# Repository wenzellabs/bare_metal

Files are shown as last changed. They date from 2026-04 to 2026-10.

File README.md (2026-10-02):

# bare_metal

**bare metal** is an FPGA development board - the ideal platform to get started with FPGAs and HDL of one or another sort. all open source.

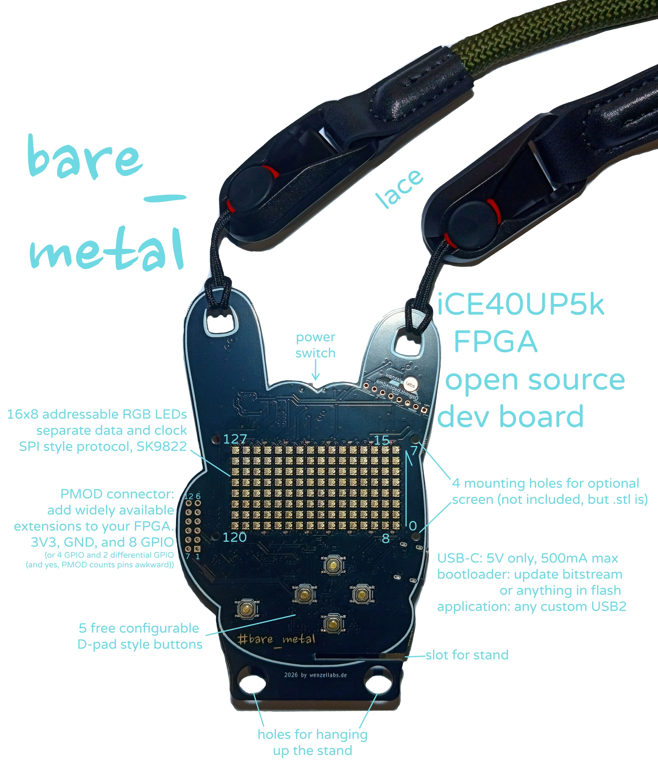
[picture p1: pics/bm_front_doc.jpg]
a black PCB (front) in the shape of a hand showing the metal horn, features are documented


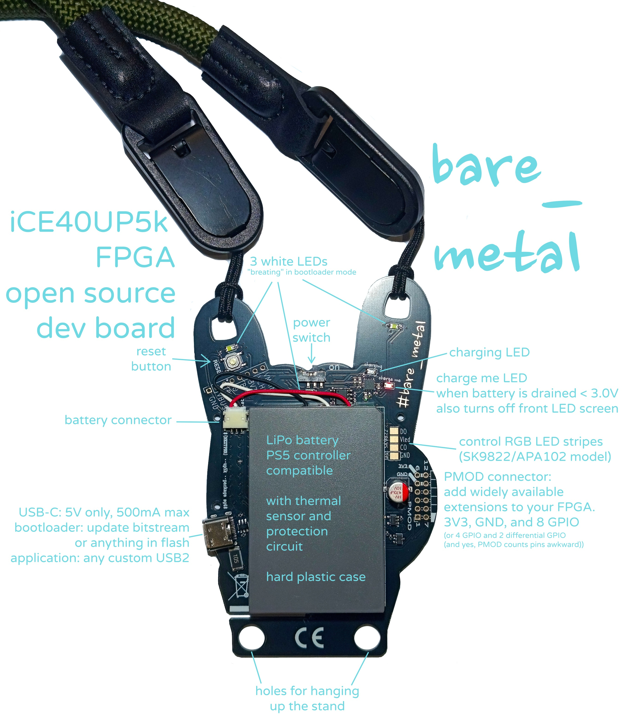
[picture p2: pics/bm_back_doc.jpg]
a black PCB (back) in the shape of a hand showing the metal horn, features are documented


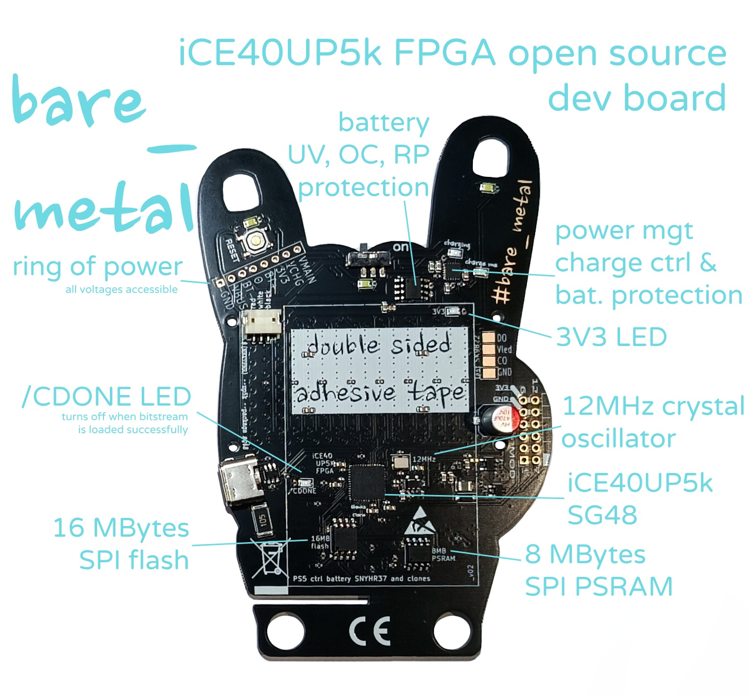
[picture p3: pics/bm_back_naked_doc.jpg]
a black PCB (back, without battery) in the shape of a hand showing the metal horn, features are documented


bare_metal, the opensource FPGA development board:

- five user buttons: OK, left, right, up, down
- large 16x8 SPI-addressable RGB LEDs display
- extensible through a PMOD interface
- comes with a battery for many hours of runtime
- extensive power management, monitoring and battery protection in HW
- allows for CPU-less designs or soft-core CPUs
- get into FPGAs with the **yosys** and **nextpnr** all open source toolchains
- program in python/amarant, verilog, spade or others
- comes with a stand
- three bright white LEDs as simple debug or flashlight
- usable as name tag, comes with a lace
- comes with a bootloader as 1st of four bitstreams
- can host up to 3 user bitstreams
- 16MBytes flash in total (1 bitstream takes < 128kBytes)
- 8MBytes RAM in total
- transputer research platform, as 3 user bitstreams can "boot" each other, see `bootloader` below
- hacky but feasible: more that 3 user bitstreams (hundreds)

## tech bits

### schematic

see the [hardware](hardware/) directory. find [the schematics](hardware/bare_metal_schematic.pdf), the KiCad sources and [some](hardware/bare_metal_front.png) [nice](hardware/bare_metal_back.png) [renderings](hardware/bare_metal_3d.png).

### memory

- 16MBytes SPI flash (W25Q128JVSIQ) this is where the FPGA boots from and user storage such as text, fonts, images, sounds, video, etc.
- 8MBytes SPI PSRAM (LY68L6400) far all of your extensive memory needs

here's a memory map of the SPI flash:

```
# 0x000_0000 - 0x000_009f =160b, multiboot header, slot table
# 0x000_00a0 - 0x001_efff ~124kB, slot 0, bare_metal_bootloader
# 0x001_f000 - 0x001_ffff =4kB, bootmetadata
# 0x002_0000 - 0x003_ffff =128kB, slot 1, user bitstream, hackerstacker_demo by default
# 0x004_0000 - 0x005_ffff =128kB, slot 2, another bitstream, transputers anyone?
# 0x006_0000 - 0x007_ffff ~128kB, slot 3, yab, hooray for transputers!
# 0x008_0000 - 0x100_0000 ~15.5MB, user data, images, fonts, text, sounds, videos etc
```
```
# in hackerstacker_demo, we reserve the first 512 KB for bootloader and bitstreams,
# and use the rest for user data:
# 0x008_0000 - 0x008_ffff = 64 kB, font data
# 0x009_0000 - 0x009_ffff = 64 kB, game data
# 0x00a_0000 - 0x00a_ffff = 64 kB, nick names
# 0x00b_0000 - 0x0ff_ffff = ~15.3MB images, video
```

### bootloader

the bootloader is always started after power up or reset. it lives in slot0 of the four default bitstream slots.

the bootloader is forked from https://github.com/tinyfpga/TinyFPGA-Bootloader which looks unmaintained nowadays. we forked, and implement our bootloader and the `tinyprog` flashing tool at https://codeberg.org/wenzellabs/bare_metal_bootloader

```

                   [-----------][----------][----------]
                   [ user bit- ][ user bit-][ user bit-]
                   [ stream 1  ][ stream 2 ][ stream 3 ]
                   [           ][          ][          ]
                   [===========][==========][==========]
                   [-----------------------------------]
                   [    USB-bootloader bitstream 0     ]
                   [===================================]
               [-------------------------------------------]
               [ iCE40-up5k-sg48 FPGA, 5k LCs, DSP fn()s   ]
               [===========================================]
[-----]    [----------------------------------------------------]    [---------------]
[ USB ]----[ bare_metal, buttons, batt., LEDs, RGB-display, PMOD]----[PMOD extensions]
[=====]    [====================================================]    [===============]

```

the bootloader animates the three white LEDs `index`, `middle` and `pinky`. if the bootloader detects a host PC (if it gets USB enumerated) it stays in the bootloader and creates a cdc_acm /dev/ttyACM0 that can be used in conjunction with tinyprog to flash user bitstreams into slot1, slot2 or slot3, or any other flash content.

if no host PC is detected the bootloader "jumps" to the user bitstream in slot1.

**stay in bootloader** although there's no host PC:

- press btn_**down** while powerup/reset.

jump to **slot1** user bitstrem although we're connected to a host PC:

- press btn_**ok** while powerup/reset.

jump to **slot2** user bitstrem although we're connected to a host PC:

- press btn_**left** while powerup/reset.

jump to **slot3** user bitstrem although we're connected to a host PC:

- press btn_**right** while powerup/reset.

### examples

#### hackerstacker_demo

by default the first user bitstream in slot1 is hackerstacker_demo, that has various modes, which can be advanced by a long btn_ok press.

modes:

- hackerstacker game, control: btn_ok
- scroll user text. control: switch text: btn_ok, brightness: btn_up, btn_down, scroll-mode: btn_left, font: btn-right
- skating images. control: btn_ok
- various static patterns, rainbow, trans flag, checker board. control: btn_ok
- various animated patterns, rainbow, trans flag. control: btn_ok

the texts, fonts and images live in the SPI flash aside from the bitstream, so they can be replaced or extended without re-synthesizing the bitstream.
see [the hackerstacker_demo directory](firmware/examples/amaranth/hackerstacker_demo) and there the make targets
```
make flash-nick # see nick.txt first!
make flash-font
make flash-image # see image.txt first!
```

#### julia

reach it by pressing btn_left while powerup/reset.

by default the second user bitstream in slot2 is julia. it renders a julia set, and loops:

- pan to a random position
- zoom in until the entropy is too low
- zoom out again

the up/down/left/right control the complex coordinate C of the julia set being rendered.

the OK button changes the palette.

#### psram_probe

reach it by pressing btn_right while powerup/reset.

for now the default third user bitstream in slot3 is psram_probe, just a production PSRAM test. lights up one LED in green per pass.

I hope to get some small spade demo, looking at you @TheZoq2.

### power

#### battery

a PS5 controller compatible battery similar to SNYHR37. 2500 mAh, 1S.
the little plasic box is a nice feature to protect the pouch cell from stabbing you and vice versa.

#### USB-C

there's a current limit of 500mA in place. no USB-PD, just 5V.

the data pins are usable and available for creating any USB2 devices. the board has no dedicated USB-HW (aside from ESD protection) but anything can be implemented in the FPGA, just as the bootloader does. related pins:

```
# USB
set_io -nowarn usbp         42    # IOT_51a  - USB D+
set_io -nowarn usbn         38    # IOT_50b  - USB D-
set_io -nowarn usb_det      37    # IOT_36b  - USB_DET, active-high enables 1k5 pull-up on D+
```

#### battery protection

we turn the screen off at around 3V battery voltage to notify the user that she needs a power up. there's also a red `charge me` LED that indicates this state.
at 2.5V a hard battery protection kicks in, and everything is switched off, until charging via USB-C again.

there's also a overvoltage and overcurrent protection and thermal monitoring in place.

#### the ring of power

bare_metal wears a little ring at it's pinky, the `ring of power`.
here all various important voltages are accessible:

- 1 GND
- 2 VBUS
- 3 VBAT_MINUS
- 4 BAT_TEMP_SENSE
- 5 VBAT
- 5 3V3
- 6 VCHG
- 7 VMAIN

## the FPGA

it's a **Lattice iCE40 UP5K** in a **SG48** package

- fully supported by yosys and nextpnr
- 5000+ LUTs
- 8 DSP blocks (MULT16 with ACC32)
- 1024kBits SPRAM in 4 blocks
- 120kBits EBR memory in 30 blocks
- 2 hard I2C blocks
- 2 hard SPI blocks

## pinout

it's all in the examples and printed on the stand, but for completenes here's a PCF:

```
# bare_metal
# iCE40UP5K SG48 (QFN 48)

# this is a complete bare_metal pin definition
# you may use for your designs

# 12 MHz crystal oscillator (dedicated clock pad)
set_io -nowarn clk_12M      35    # IOT_46b_G0

# USB
set_io -nowarn usbp         42    # IOT_51a  - USB D+
set_io -nowarn usbn         38    # IOT_50b  - USB D-
set_io -nowarn usb_det      37    # IOT_36b  - USB_DET, active-high enables 1k5 pull-up on D+

# buttons
set_io -nowarn btn_ok       23    # IOT_37a
set_io -nowarn btn_up       45    # IOB_5b
set_io -nowarn btn_down     11    # IOB_20a
set_io -nowarn btn_left     44    # IOB_3b_G6
set_io -nowarn btn_right    10    # IOB_18a

# LED indicators - three white LEDs, low active
set_io -nowarn led_index    39    # white_index
set_io -nowarn led_middle   40    # white_middle
set_io -nowarn led_pinky    41    # white_pinky

# SPI configuration flash
set_io -nowarn spi_mosi     14    # IOB_32a - SPI_SO, MOSI
set_io -nowarn spi_miso     17    # IOB_33b - SPI_SI, MISO
set_io -nowarn spi_clk      15    # IOB_34a - SPI_SCK
set_io -nowarn spi_csn_flash 16   # IOB_35b - SPI_CSn_FLASH
set_io -nowarn spi_wp       18    # IOB_31b - SPI_WPn
set_io -nowarn spi_hold     19    # IOB_29b - SPI_HOLDn

# SPI PSRAM, same as above, just CSn
set_io -nowarn spi_csn_ram   6    # IOB_13b - SPI_CSn_RAM

# SK9822 / APA102-compatible LED matrix (128 LEDs, 16x8)
set_io -nowarn led_di        4    # IOB_8a
set_io -nowarn led_ci        3    # IOB_9b

# LED matrix power enable
set_io -nowarn led_power_on 46    # IOB_0a

# PMOD interface - mind the special pin numbering of PMOD interfaces!
set_io -nowarn -pullup yes pmod_a_n     27   # PMOD pin 1
set_io -nowarn -pullup yes pmod_a_p     26   # PMOD pin 7
set_io -nowarn -pullup yes pmod_2       25   # PMOD pin 2
set_io -nowarn -pullup yes pmod_8       28   # PMOD pin 8
set_io -nowarn -pullup yes pmod_b_p     32   # PMOD pin 3
set_io -nowarn -pullup yes pmod_b_n     31   # PMOD pin 9
set_io -nowarn -pullup yes pmod_4       13   # PMOD pin 4
set_io -nowarn -pullup yes pmod_10      12   # PMOD pin 10

```

## stand

the stand can serve multiple purposes

it conveniently lists all PMOD and all other pins.

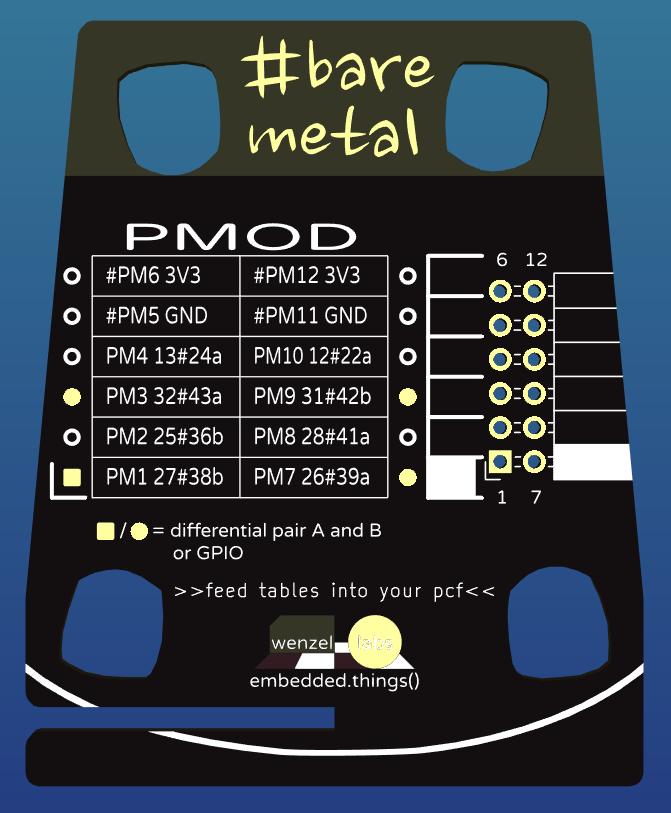
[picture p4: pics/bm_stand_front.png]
a black PCB (front) with pin tabled printed on


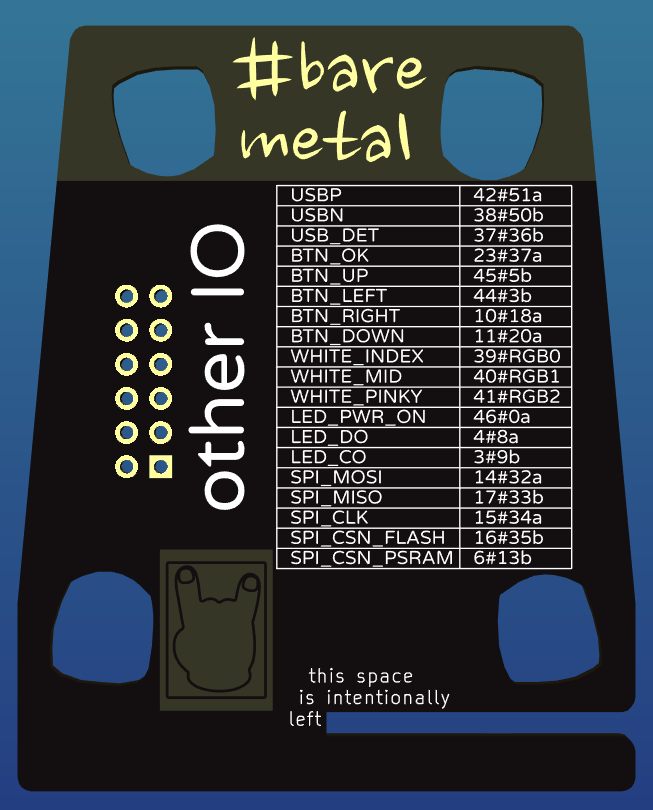
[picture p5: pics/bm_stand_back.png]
a black PCB (back) with pin tabled printed on


use it to display the bare_metal board, by sliding the two slots into each other.

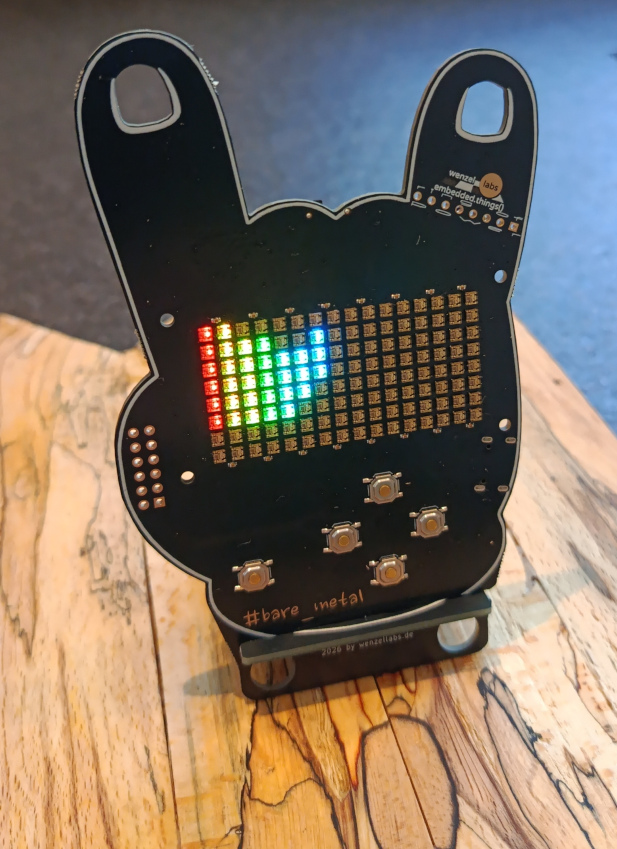
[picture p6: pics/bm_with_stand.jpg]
a black PCB standing on a table


or when hanging the bare_metal around your neck (or elsewhere) you can hang the stand into the bottom holes, the stand then mimicks a sleeve.

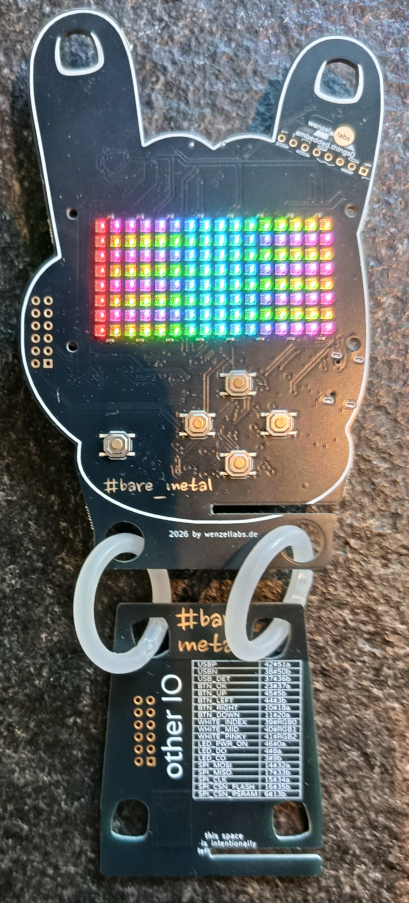
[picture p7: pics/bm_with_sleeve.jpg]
a black hand shaped PCB with a 2nd sleeve shaped PCB


## what's included?

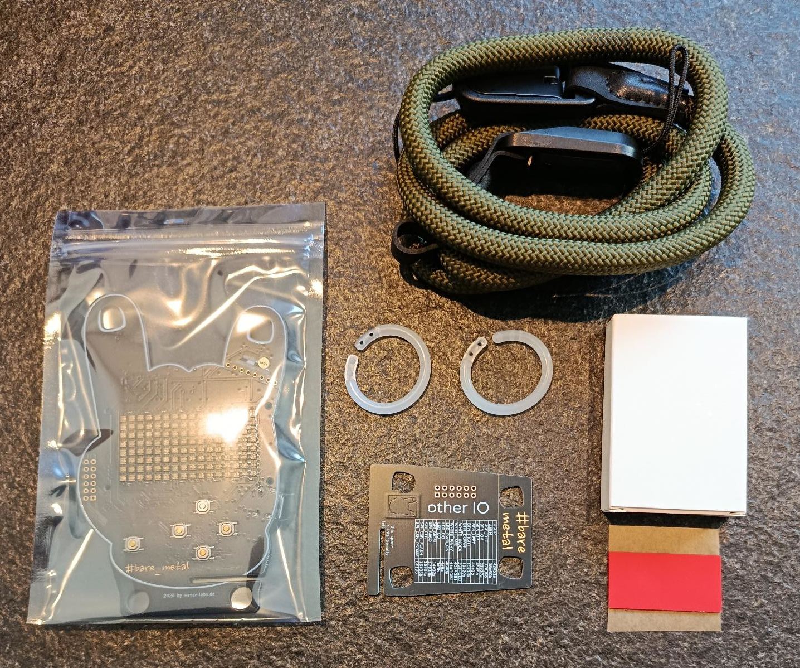
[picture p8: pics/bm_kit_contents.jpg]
the contents in the bare_metal kit


- bare_metal main board
- rugged lace, detachable
- two soft plastic rings to hang bare_metal and its stand together
- the bare_metal stand PCB
- the 1S LiPo battery
- double sided adhesive tape to mount the battery on the bare_metal main board

## license

Copyright (c) 2026 m. wenzel, wenzellabs

Unless otherwise stated, the hardware designs, firmware source code,
and documentation in this repository are licensed under:

Creative Commons Attribution-NonCommercial-ShareAlike 4.0 International
(CC BY-NC-SA 4.0)

https://creativecommons.org/licenses/by-nc-sa/4.0/

Commercial use, including commercial manufacture, sale, or distribution
of products based on these materials, is not permitted without
separate permission from the copyright holder.

see LICENSE.txt

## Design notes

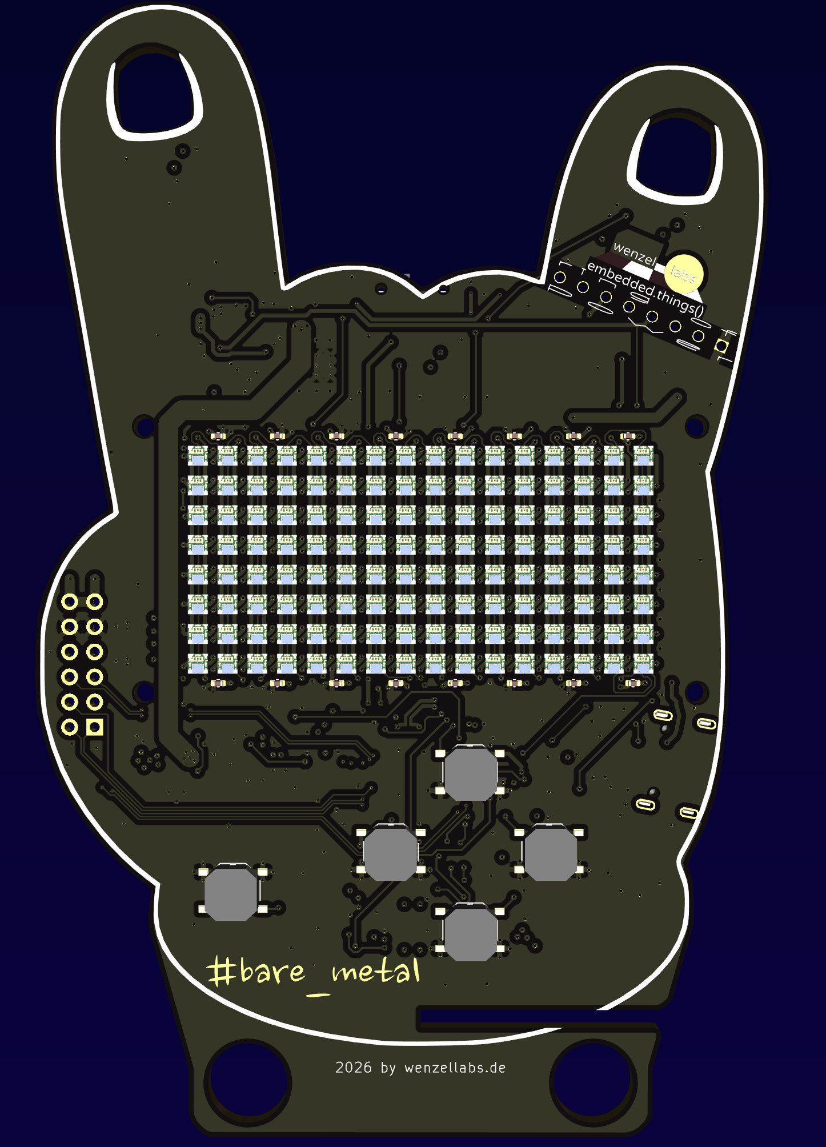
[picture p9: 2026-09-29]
hardware/bare_metal_front.png

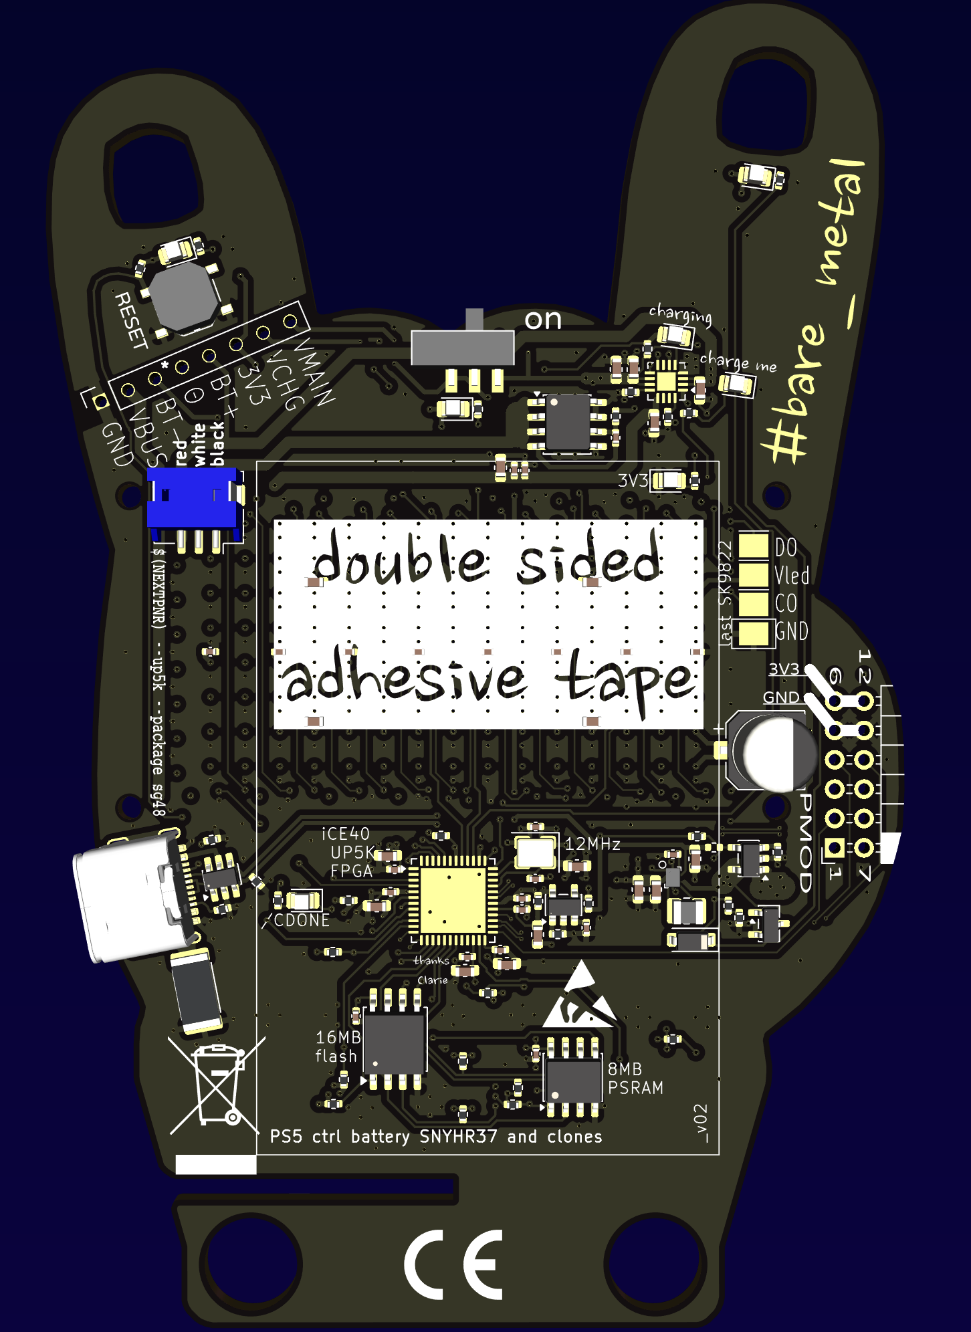
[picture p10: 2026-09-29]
hardware/bare_metal_back.png

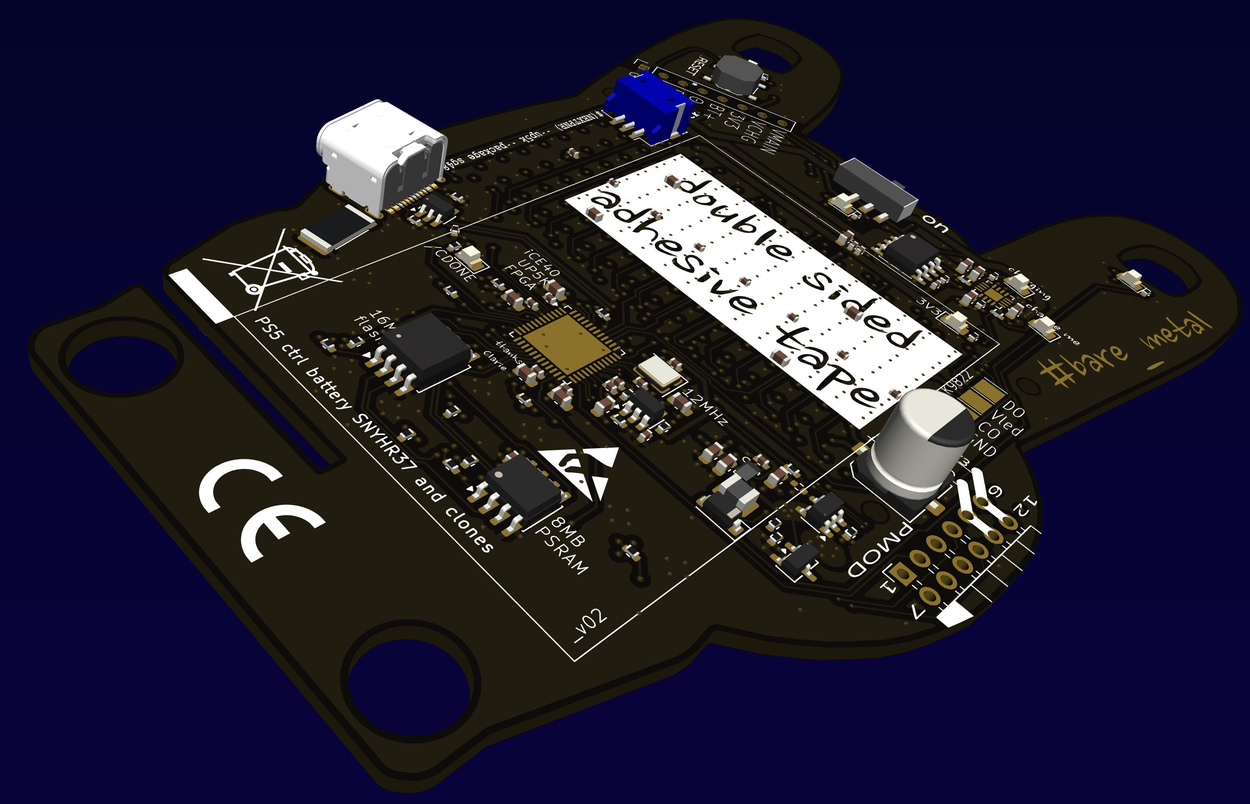
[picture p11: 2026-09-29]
hardware/bare_metal_3d.png

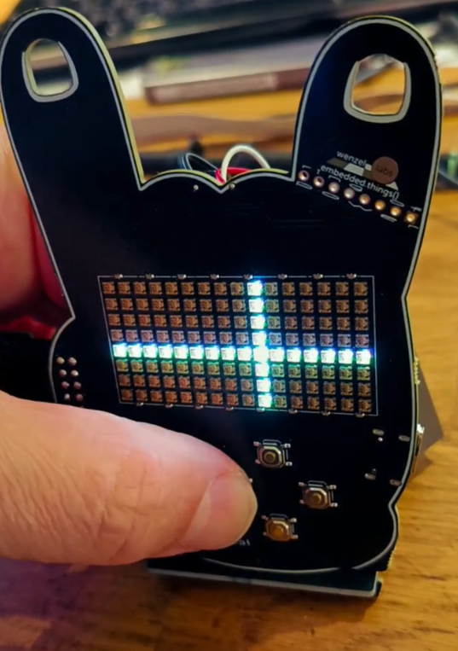
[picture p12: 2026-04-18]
pics/bm_upcoming.png

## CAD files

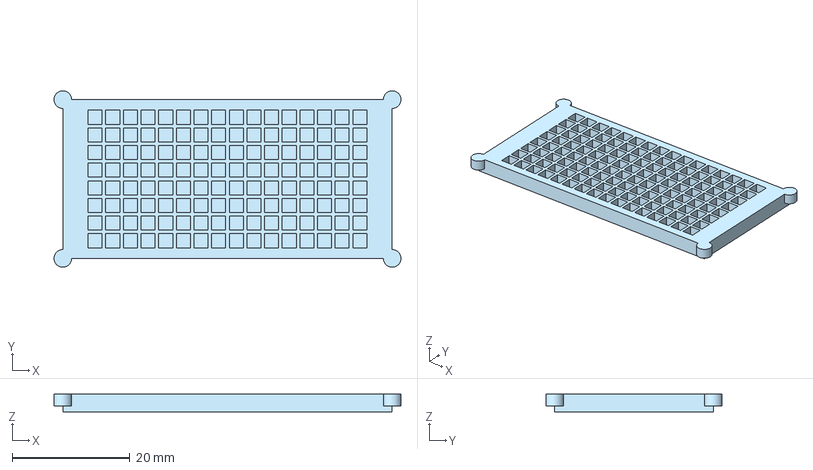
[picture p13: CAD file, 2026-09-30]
3d/bare_metal_screen_2_1.step
59.0 x 30.0 x 3.00 mm

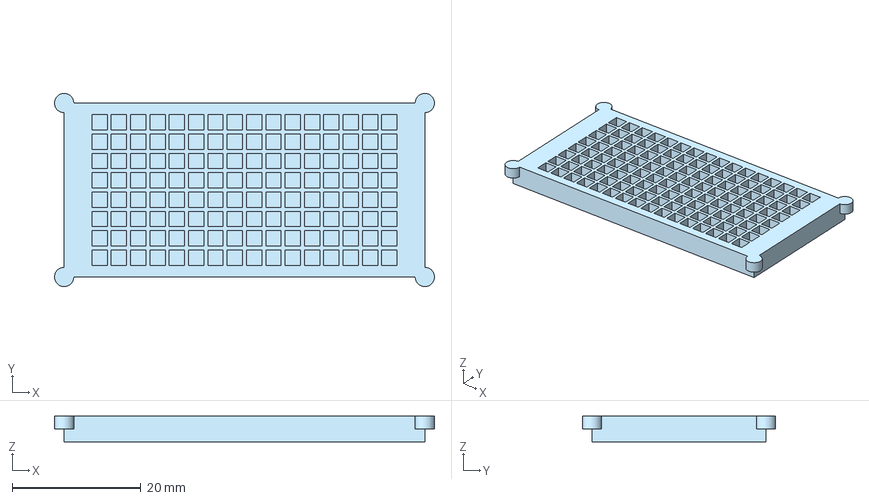
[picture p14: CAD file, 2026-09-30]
3d/bare_metal_screen_2_2.step
59.0 x 30.0 x 4.00 mm

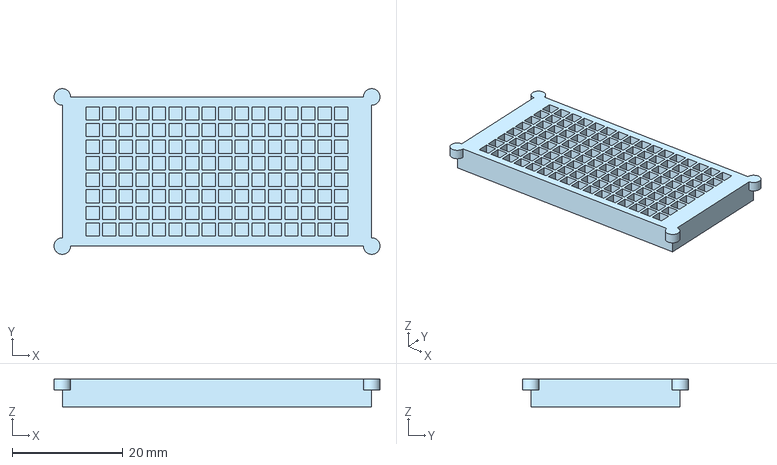
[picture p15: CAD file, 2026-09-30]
3d/bare_metal_screen_2_3.step
59.0 x 30.0 x 5.00 mm

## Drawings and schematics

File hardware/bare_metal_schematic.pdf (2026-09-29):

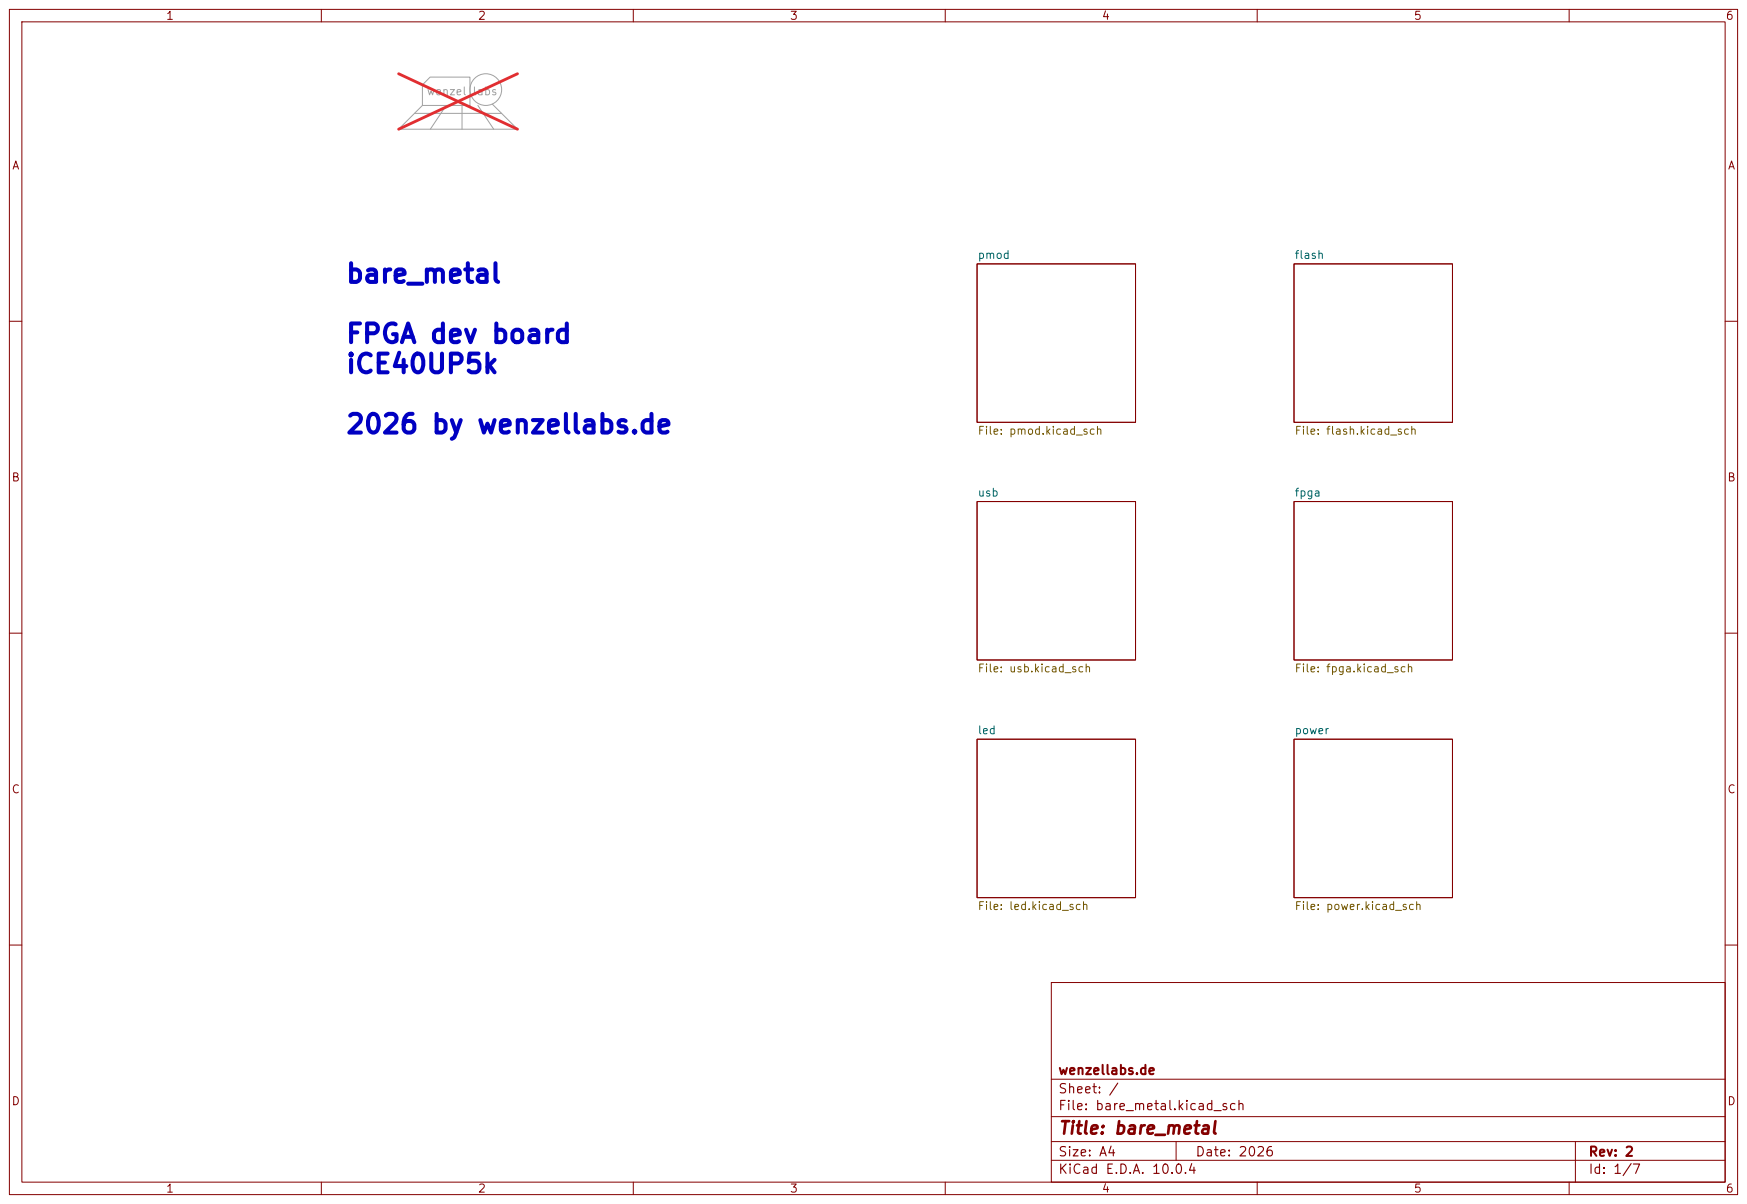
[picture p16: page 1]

File: flash.kicad_sch wenzel labs bare_metal

Size: A4 | Rev: 2
KiCad E.D.A. 10.0.4 | Id: 1/7

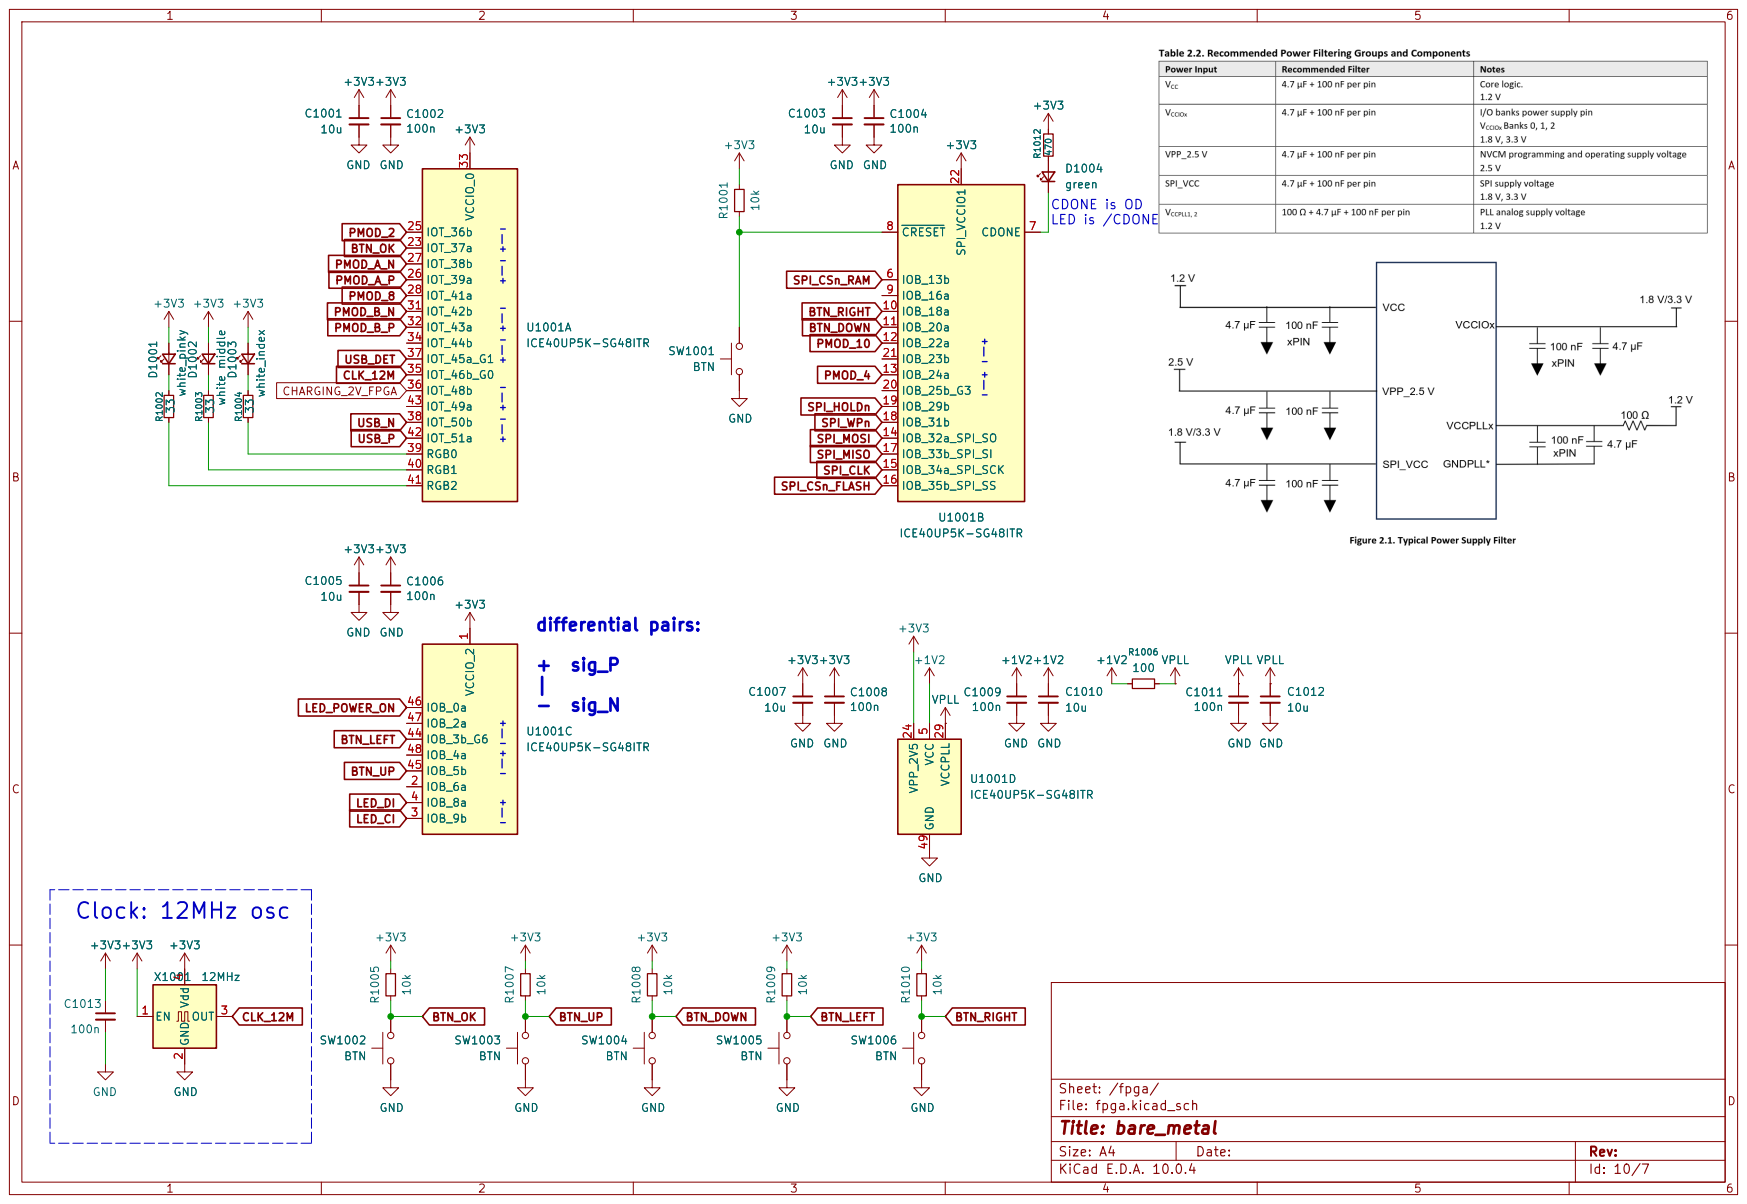
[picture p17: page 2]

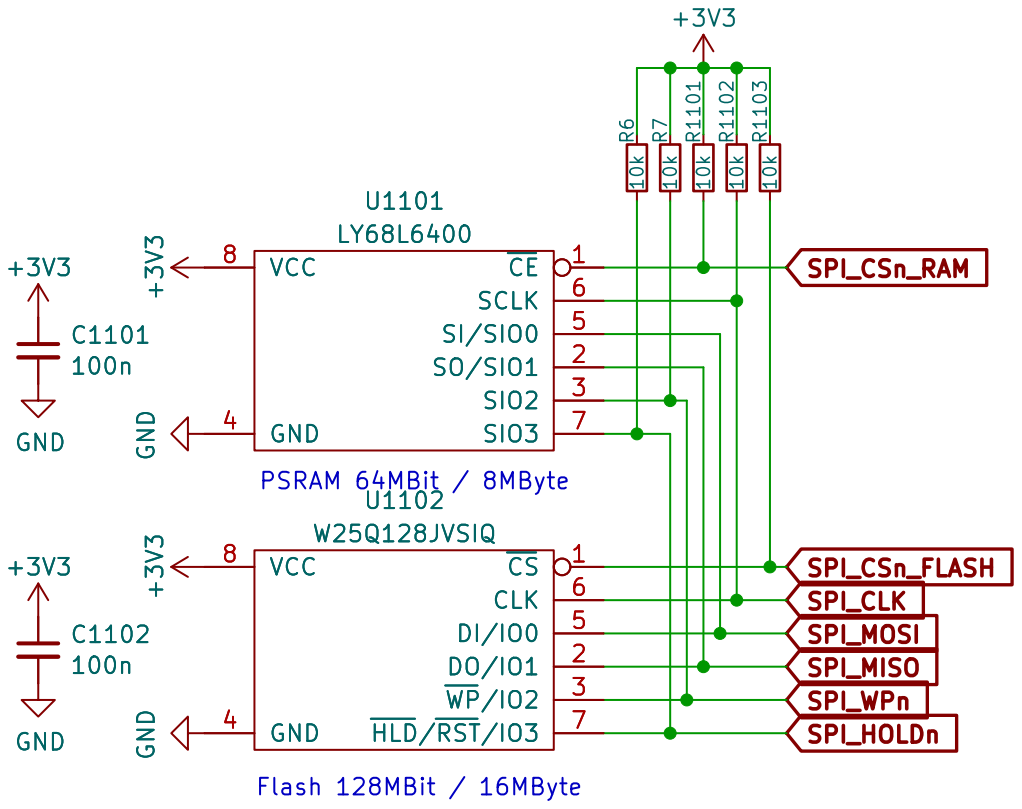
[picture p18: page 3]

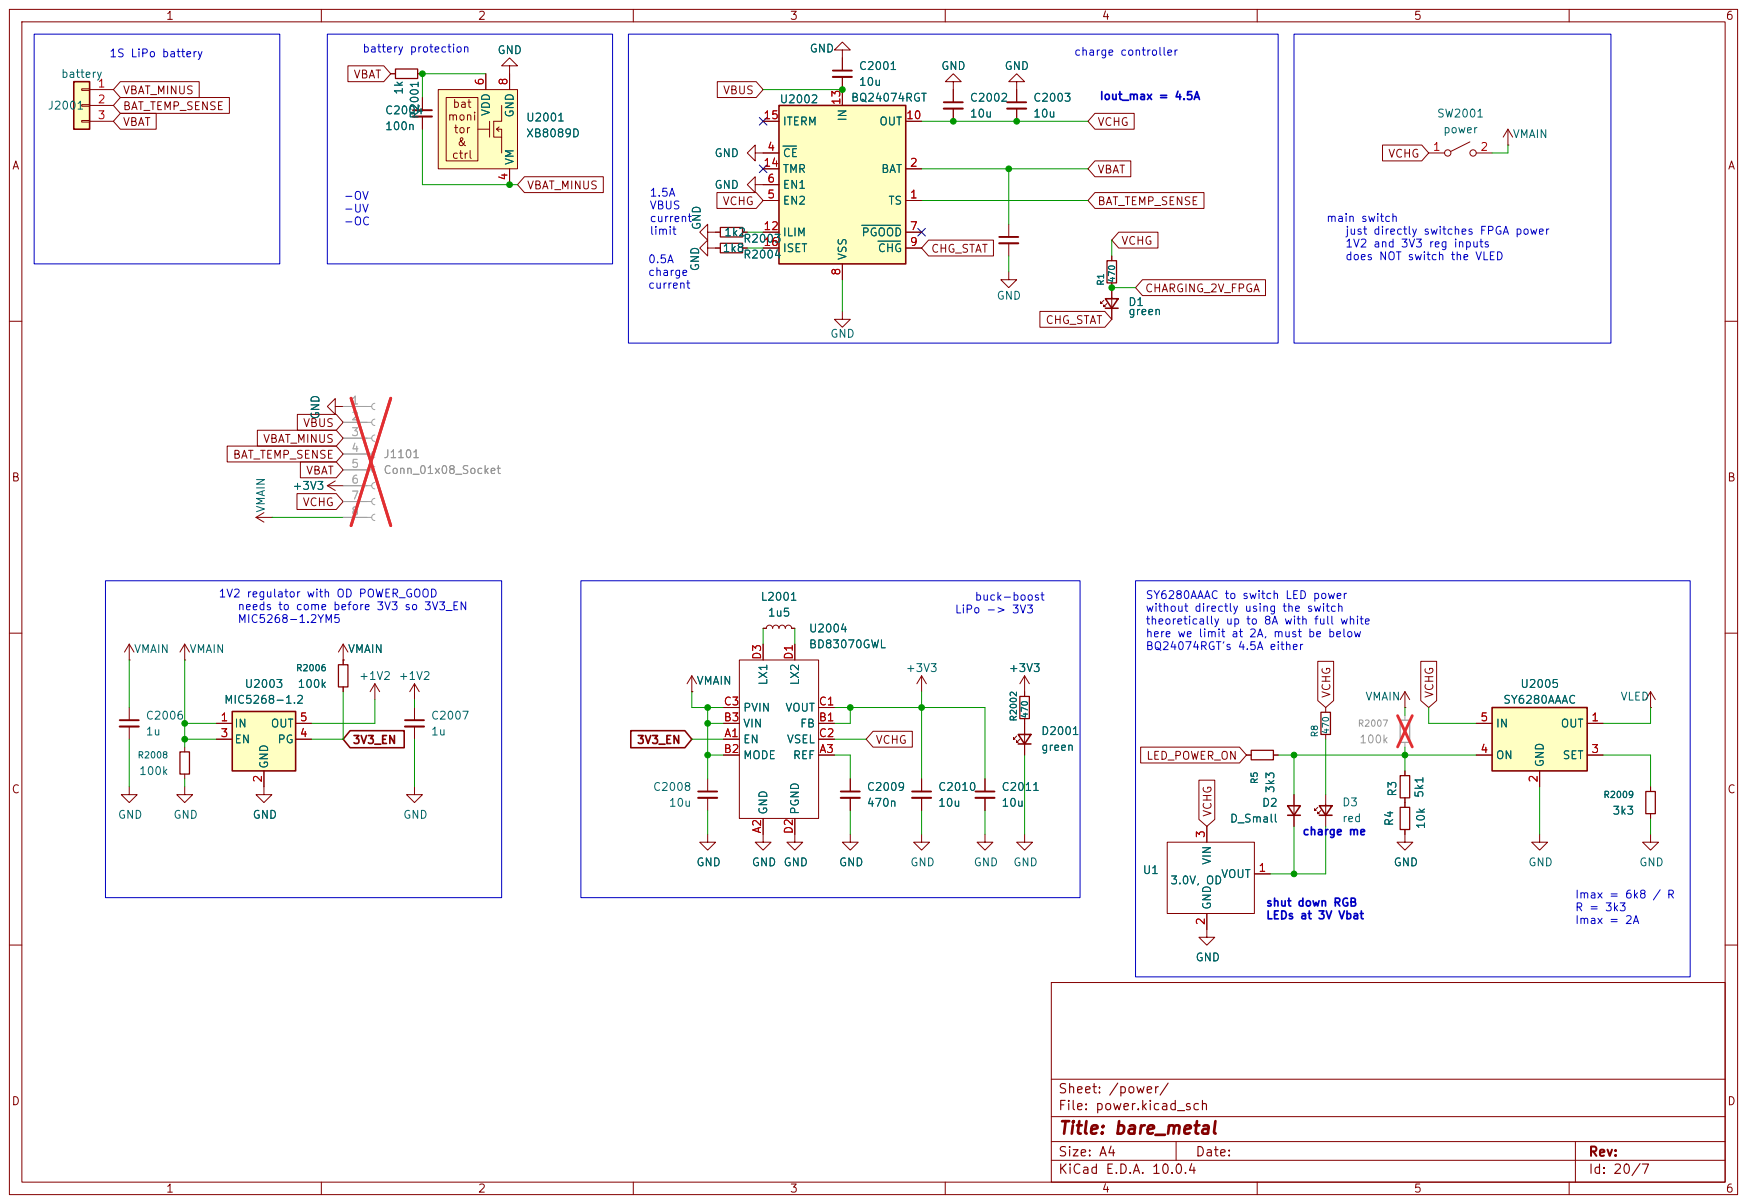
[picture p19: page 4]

4 VDD
-OV -UV -OC GND +3V3

just directly switches FPGA power 1V2 and 3V3 reg inputs does NOT switch the VLED

needs to come before 3V3 so 3V3_EN MIC5268-1.2YM5

SY6280AAAC to switch LED power without directly using the switch

theoretically up to 8A with full white here we limit at 2A, must be below

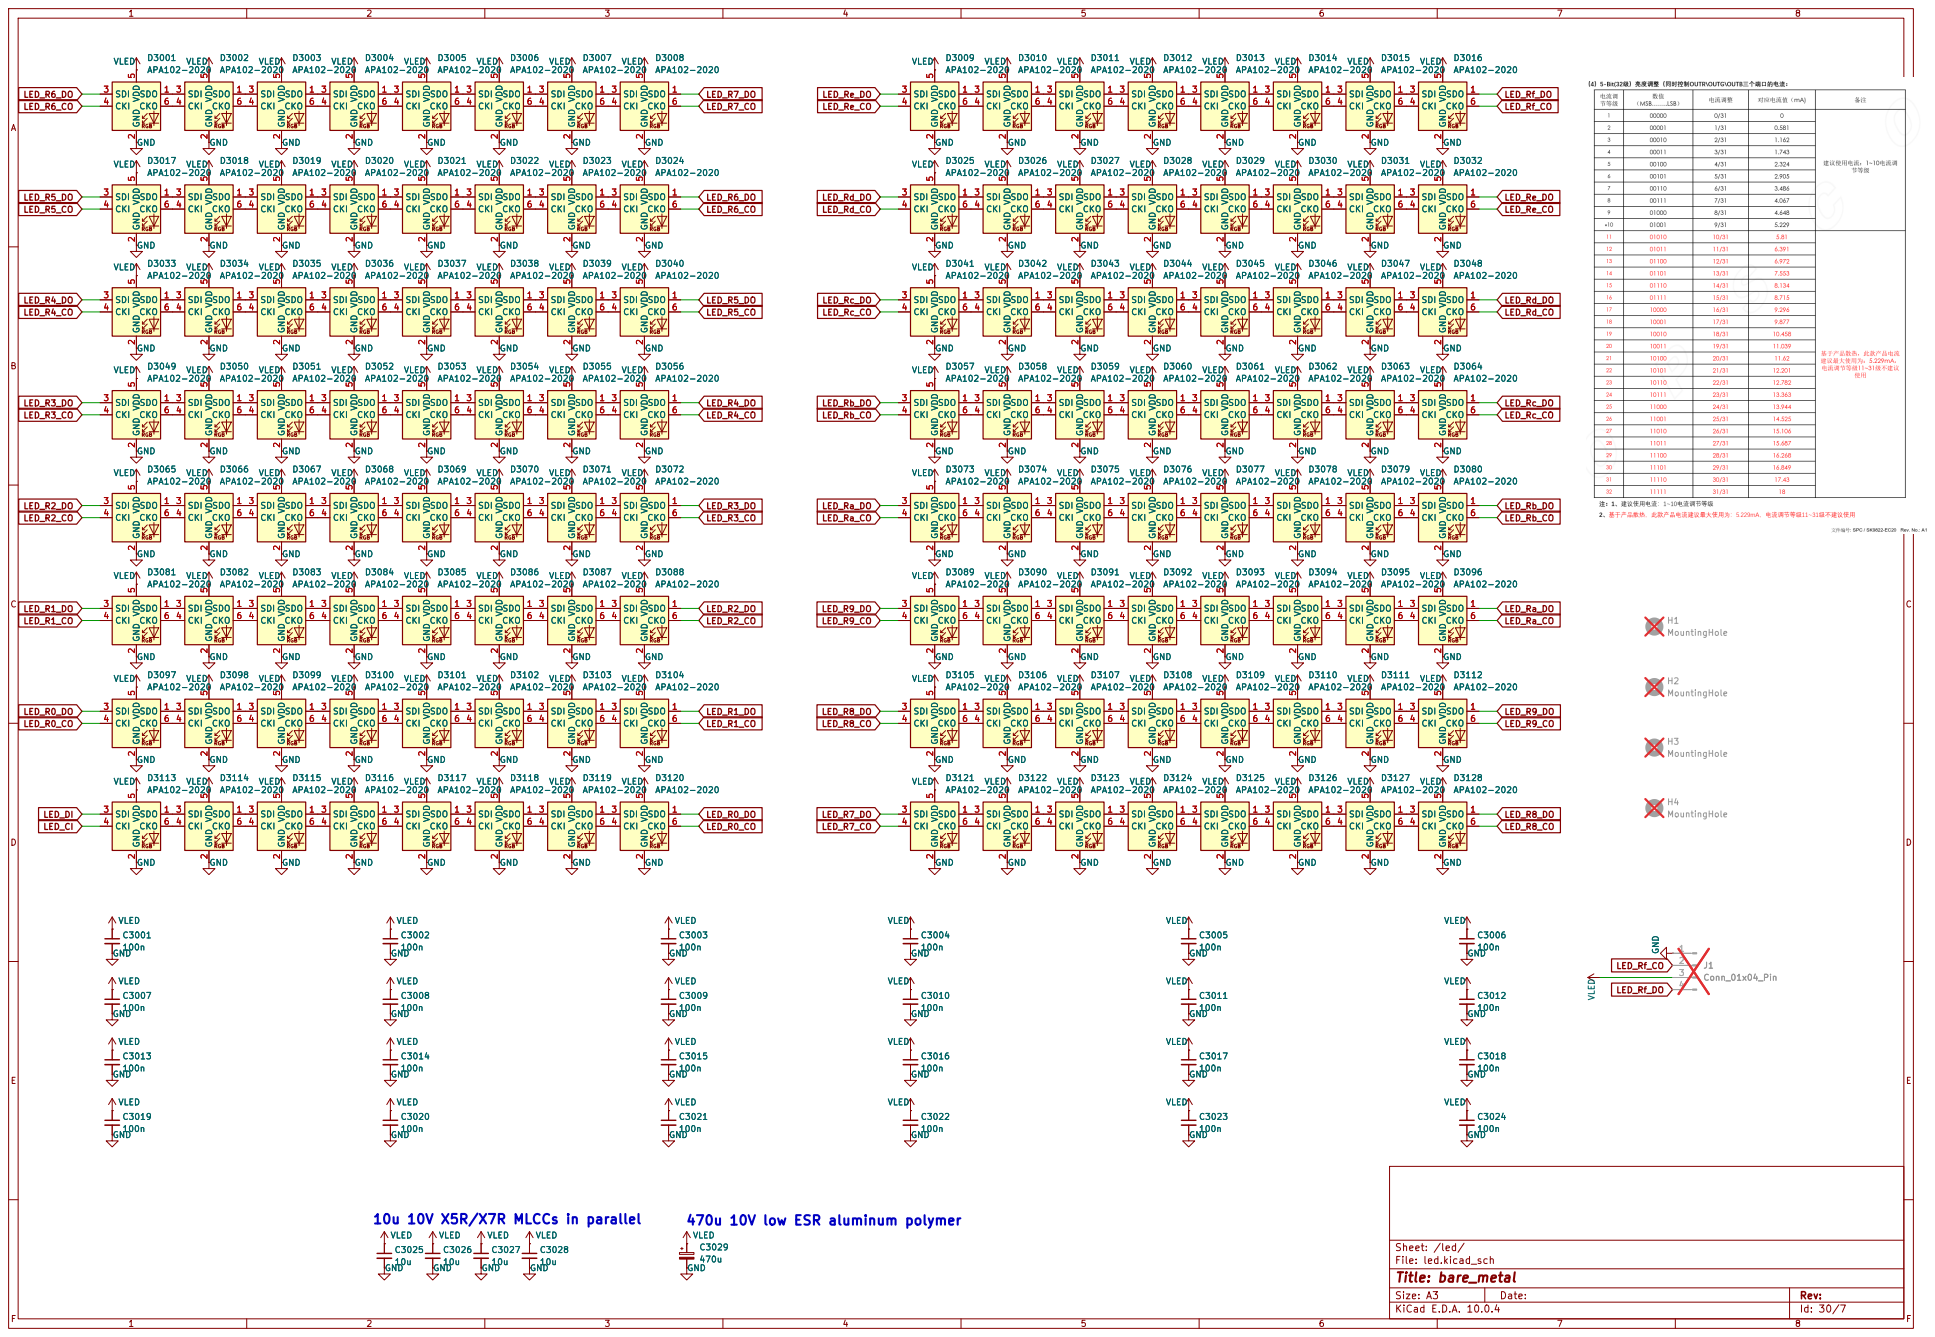
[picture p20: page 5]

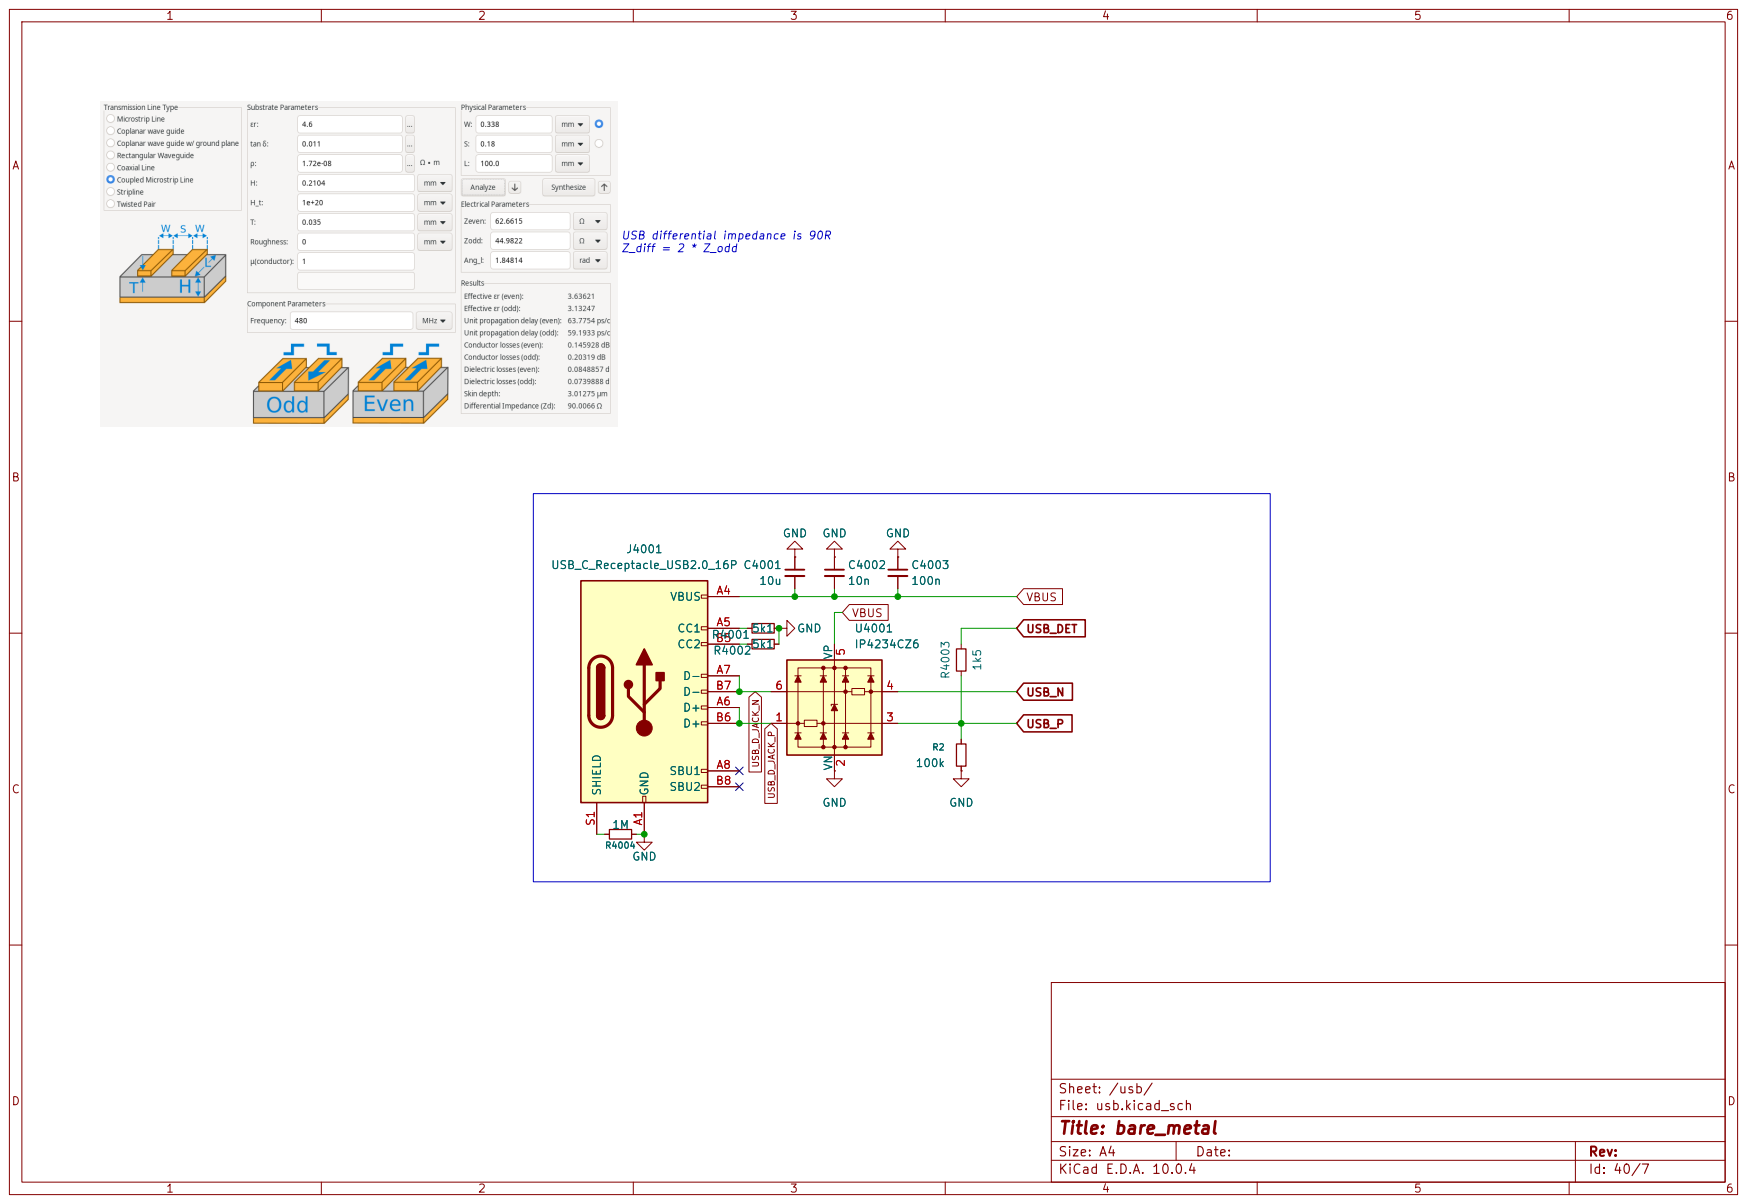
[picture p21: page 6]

VBUS USB_P USB differential impedance is 90R
Z_diff = 2 * Z_odd

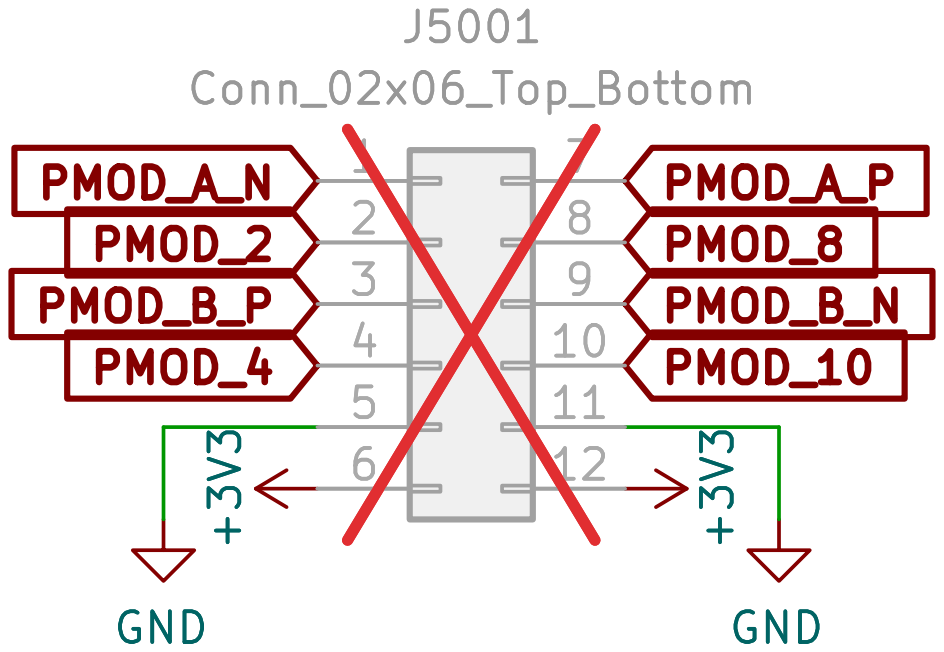
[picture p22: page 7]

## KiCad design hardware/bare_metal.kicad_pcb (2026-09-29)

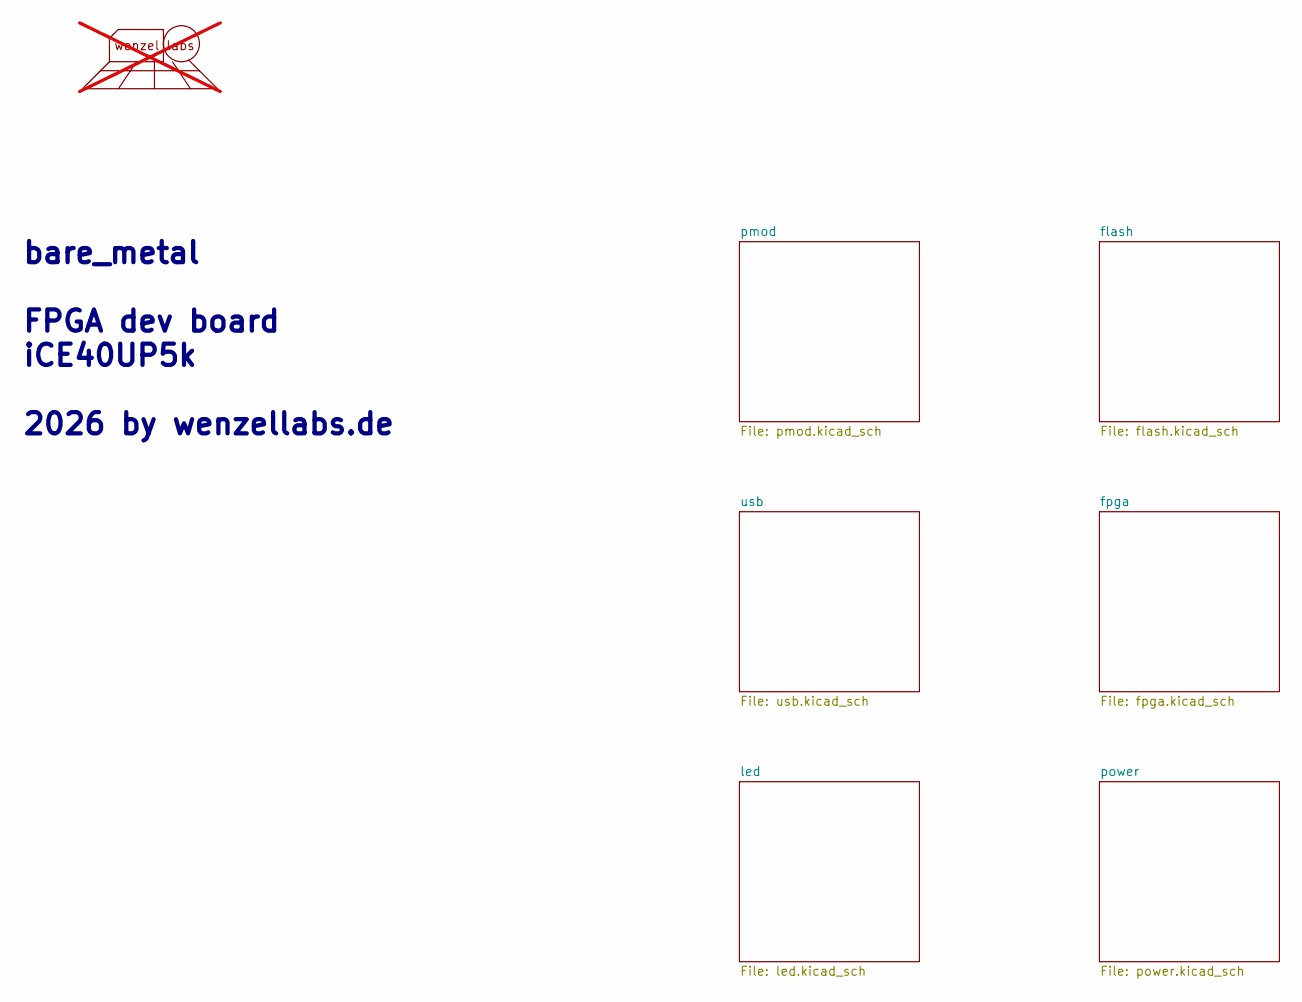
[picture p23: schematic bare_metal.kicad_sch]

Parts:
L101: Logo wenzellabs; wenzellabs_logo_v1_13x6; not fitted

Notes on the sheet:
bare_metal FPGA dev board iCE40UP5k 2026 by wenzellabs.de

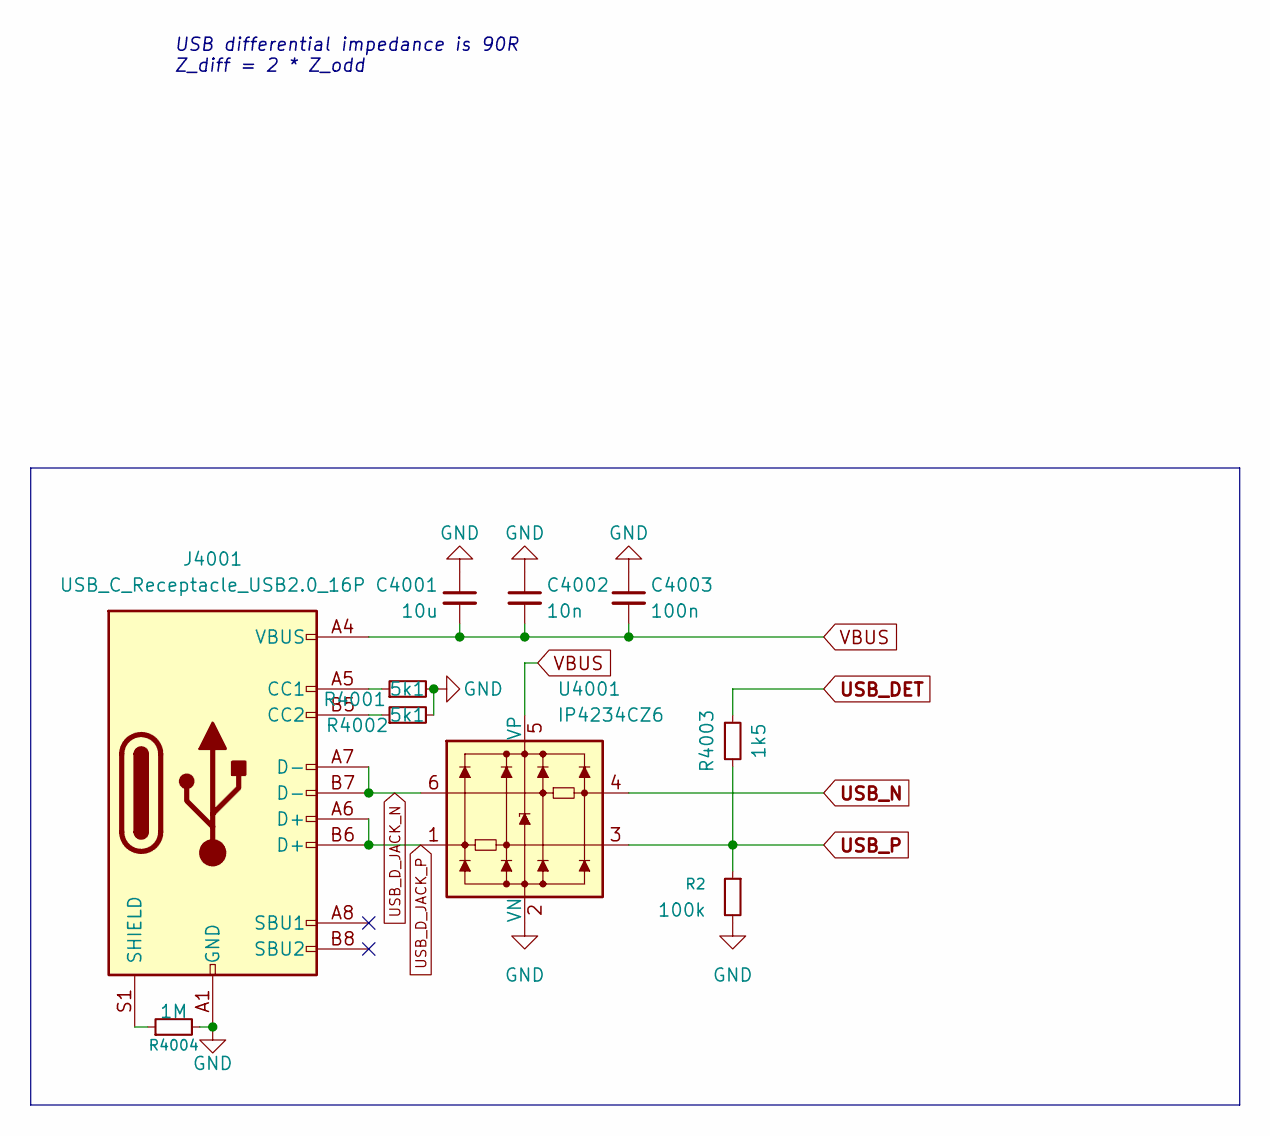
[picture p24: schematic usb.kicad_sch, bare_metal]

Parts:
C4001: 10u; C_0603_1608Metric
C4002: 10n; C_0402_1005Metric
C4003: 100n; C_0402_1005Metric
J4001: USB_C_Receptacle_USB2.0_16P; USB_C_Receptacle_GCT_USB4800-03-A_16P_TopMnt_Horizontal
R2: 100k; R_0402_1005Metric
R4001, R4002: 5k1; R_0402_1005Metric
R4003: 1k5; R_0402_1005Metric
R4004: 1M; R_2512_6332Metric
U4001: IP4234CZ6; SC-74-6_1.55x2.9mm_P0.95mm

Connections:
GND: C4001.1, C4002.1, C4003.1, J4001.A1 (GND), J4001.A12 (GND), J4001.B1 (GND), J4001.B12 (GND), R2.2, R4001.2, R4002.2, R4004.2, U4001.2 (VN); also elsewhere on the board
unnamed: J4001.A5 (CC1), R4001.1
unnamed: J4001.B5 (CC2), R4002.1
unnamed: J4001.S1 (SHIELD), R4004.1
USB_DET: R4003.1; also elsewhere on the board
USB_D_JACK_N: J4001.A7 (D-), J4001.B7 (D-), U4001.6
USB_D_JACK_P: J4001.A6 (D+), J4001.B6 (D+), U4001.1
USB_N: U4001.4; also elsewhere on the board
USB_P: R2.1, R4003.2, U4001.3; also elsewhere on the board
VBUS: C4001.2, C4002.2, C4003.2, J4001.A4 (VBUS), J4001.A9 (VBUS), J4001.B4 (VBUS), J4001.B9 (VBUS), U4001.5 (VP); also elsewhere on the board

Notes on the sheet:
USB differential impedance is 90R Z_diff = 2 * Z_odd

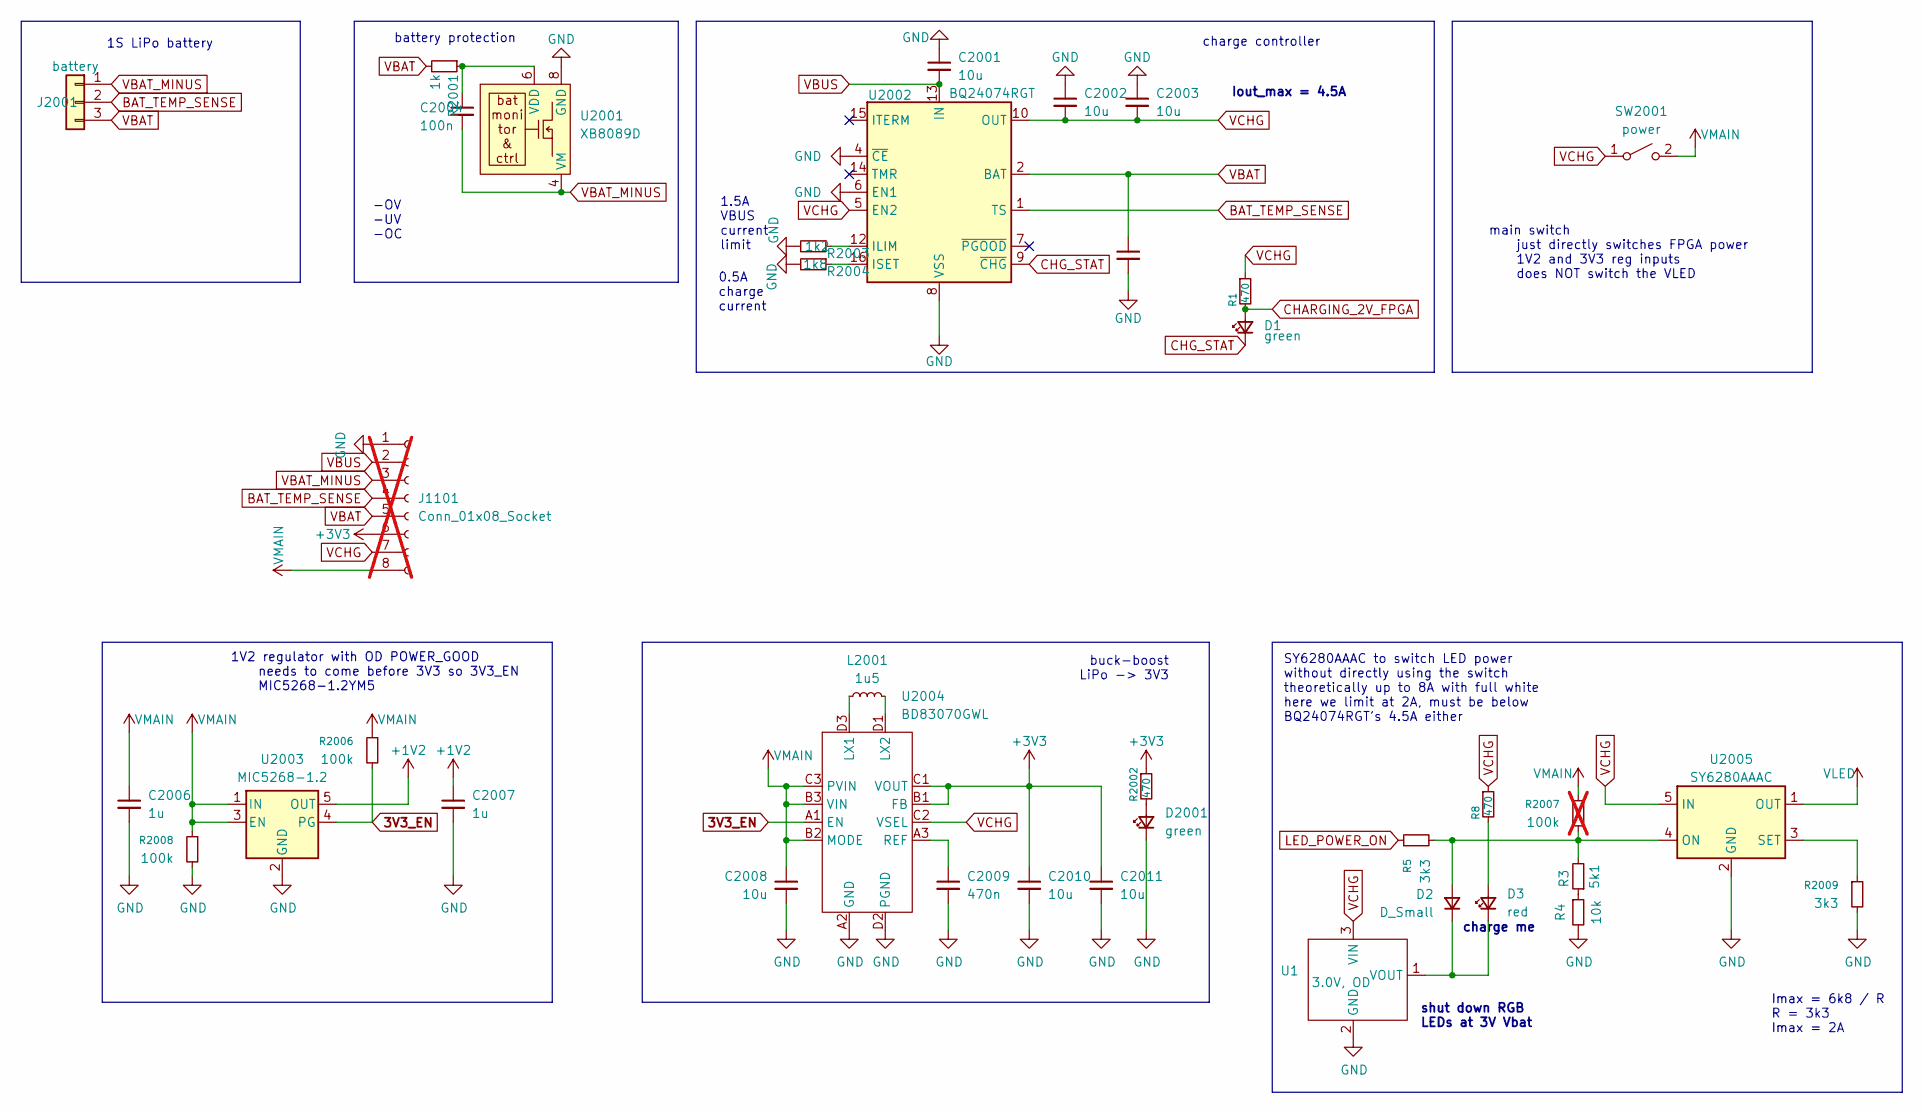
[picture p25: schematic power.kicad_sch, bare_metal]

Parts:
C2001, C2002, C2003, C2005, C2008, C2010, C2011: 10u; C_0603_1608Metric
C2004: 100n; C_0402_1005Metric
C2006, C2007: 1u; C_0402_1005Metric
C2009: 470n; C_0402_1005Metric
D1, D2001: green; LED_0805_2012Metric
D2: D_Small; D_SOD-123
D3: red; LED_0805_2012Metric
J1101: Conn_01x08_Socket; PinSocket_1x08_P2.54mm_Vertical; not fitted
J2001: battery; JST_ZH_S3B-ZR-SM4A-TF_1x03-1MP_P1.50mm_Horizontal
L2001: 1u5; L_1008_2520Metric
R1, R8, R2002: 470; R_0402_1005Metric
R3: 5k1; R_0402_1005Metric
R4: 10k; R_0402_1005Metric
R5, R2009: 3k3; R_0402_1005Metric
R2001: 1k; R_0402_1005Metric
R2003: 1k2; R_0402_1005Metric
R2004: 1k8; R_0402_1005Metric
R2006, R2008: 100k; R_0402_1005Metric
R2007: 100k; R_0402_1005Metric; not fitted
SW2001: power; diptronics_switch_SS3-CM
U1: 3.0V, OD; SOT-23-3
U2001: XB8089D; SOIC-8-1EP_3.9x4.9mm_P1.27mm_EP2.62x3.51mm_ThermalVias
U2002: BQ24074RGT; VQFN-16-1EP_3x3mm_P0.5mm_EP1.6x1.6mm
U2003: MIC5268-1.2; SOT-23-5
U2004: BD83070GWL; UCSP50L1C
U2005: SY6280AAAC; SOT-23-5

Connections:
3V3_EN: R2006.2, U2003.4 (PG), U2004.A1 (EN)
+1V2: C2007.1, U2003.5 (OUT); also elsewhere on the board
+3V3: C2010.1, C2011.1, J1101.6, R2002.1, U2004.B1 (FB), U2004.C1 (VOUT); also elsewhere on the board
BAT_TEMP_SENSE: J1101.4, J2001.2, U2002.1 (TS)
CHARGING_2V_FPGA: D1.2 (A), R1.2; also elsewhere on the board
CHG_STAT: D1.1 (K), U2002.9 (~CHG)
GND: C2001.1, C2002.1, C2003.1, C2005.2, C2006.2, C2007.2, C2008.2, C2009.2, C2010.2, C2011.2, D2001.1 (K), J1101.1, R4.2, R2003.2, R2004.2, R2008.2, R2009.2, U1.2 (GND), U2001.5 (GND), U2001.7 (GND), U2001.8 (GND), U2001.9 (GND), U2002.4 (~CE), U2002.6 (EN1), U2002.8 (VSS), U2002.17 (VSS), U2003.2 (GND), U2004.A2 (GND), U2004.D2 (PGND), U2005.2 (GND); also elsewhere on the board
LED_POWER_ON: R5.1; also elsewhere on the board
unnamed: D2.2 (A), R3.2, R5.2, R2007.2, U2005.4 (ON)
unnamed: D2.1 (K), D3.1 (K), U1.1 (VOUT)
unnamed: D3.2 (A), R8.2
unnamed: D2001.2 (A), R2002.2
unnamed: R3.1, R4.1
unnamed: C2004.1, R2001.1, U2001.6 (VDD)
unnamed: R2003.1, U2002.12 (ILIM)
unnamed: R2004.1, U2002.16 (ISET)
unnamed: L2001.1, U2004.D3 (LX1)
unnamed: L2001.2, U2004.D1 (LX2)
unnamed: C2009.1, U2004.A3 (REF)
unnamed: R2009.1, U2005.3 (SET)
VBAT: C2005.1, J1101.5, J2001.3, R2001.2, U2002.2 (BAT), U2002.3 (BAT)
VBAT_MINUS: C2004.2, J1101.3, J2001.1, U2001.1 (VM), U2001.2 (VM), U2001.3 (VM), U2001.4 (VM)
VBUS: C2001.2, J1101.2, U2002.13 (IN); also elsewhere on the board
VCHG: C2002.2, C2003.2, J1101.7, R1.1, R8.1, SW2001.1 (A), U1.3 (VIN), U2002.5 (EN2), U2002.10 (OUT), U2002.11 (OUT), U2004.C2 (VSEL), U2005.5 (IN)
VLED: U2005.1 (OUT); also elsewhere on the board
VMAIN: C2006.1, C2008.1, J1101.8, R2006.1, R2007.1, R2008.1, SW2001.2 (B), U2003.1 (IN), U2003.3 (EN), U2004.B2 (MODE), U2004.B3 (VIN), U2004.C3 (PVIN)

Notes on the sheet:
1S LiPo battery
main switch just directly switches FPGA power 1V2 and 3V3 reg inputs does NOT switch the VLED
battery protection
SY6280AAAC to switch LED power without directly using the switch theoretically up to 8A with full white here we limit at 2A, must be below BQ24074RGT's 4.5A either
charge controller
Imax = 6k8 / R R = 3k3 Imax = 2A
0.5A charge current
1V2 regulator with OD POWER_GOOD needs to come before 3V3 so 3V3_EN MIC5268-1.2YM5
buck-boost LiPo -> 3V3
Iout_max = 4.5A
-OV -UV -OC
charge me
shut down RGB LEDs at 3V Vbat
1.5A VBUS current limit

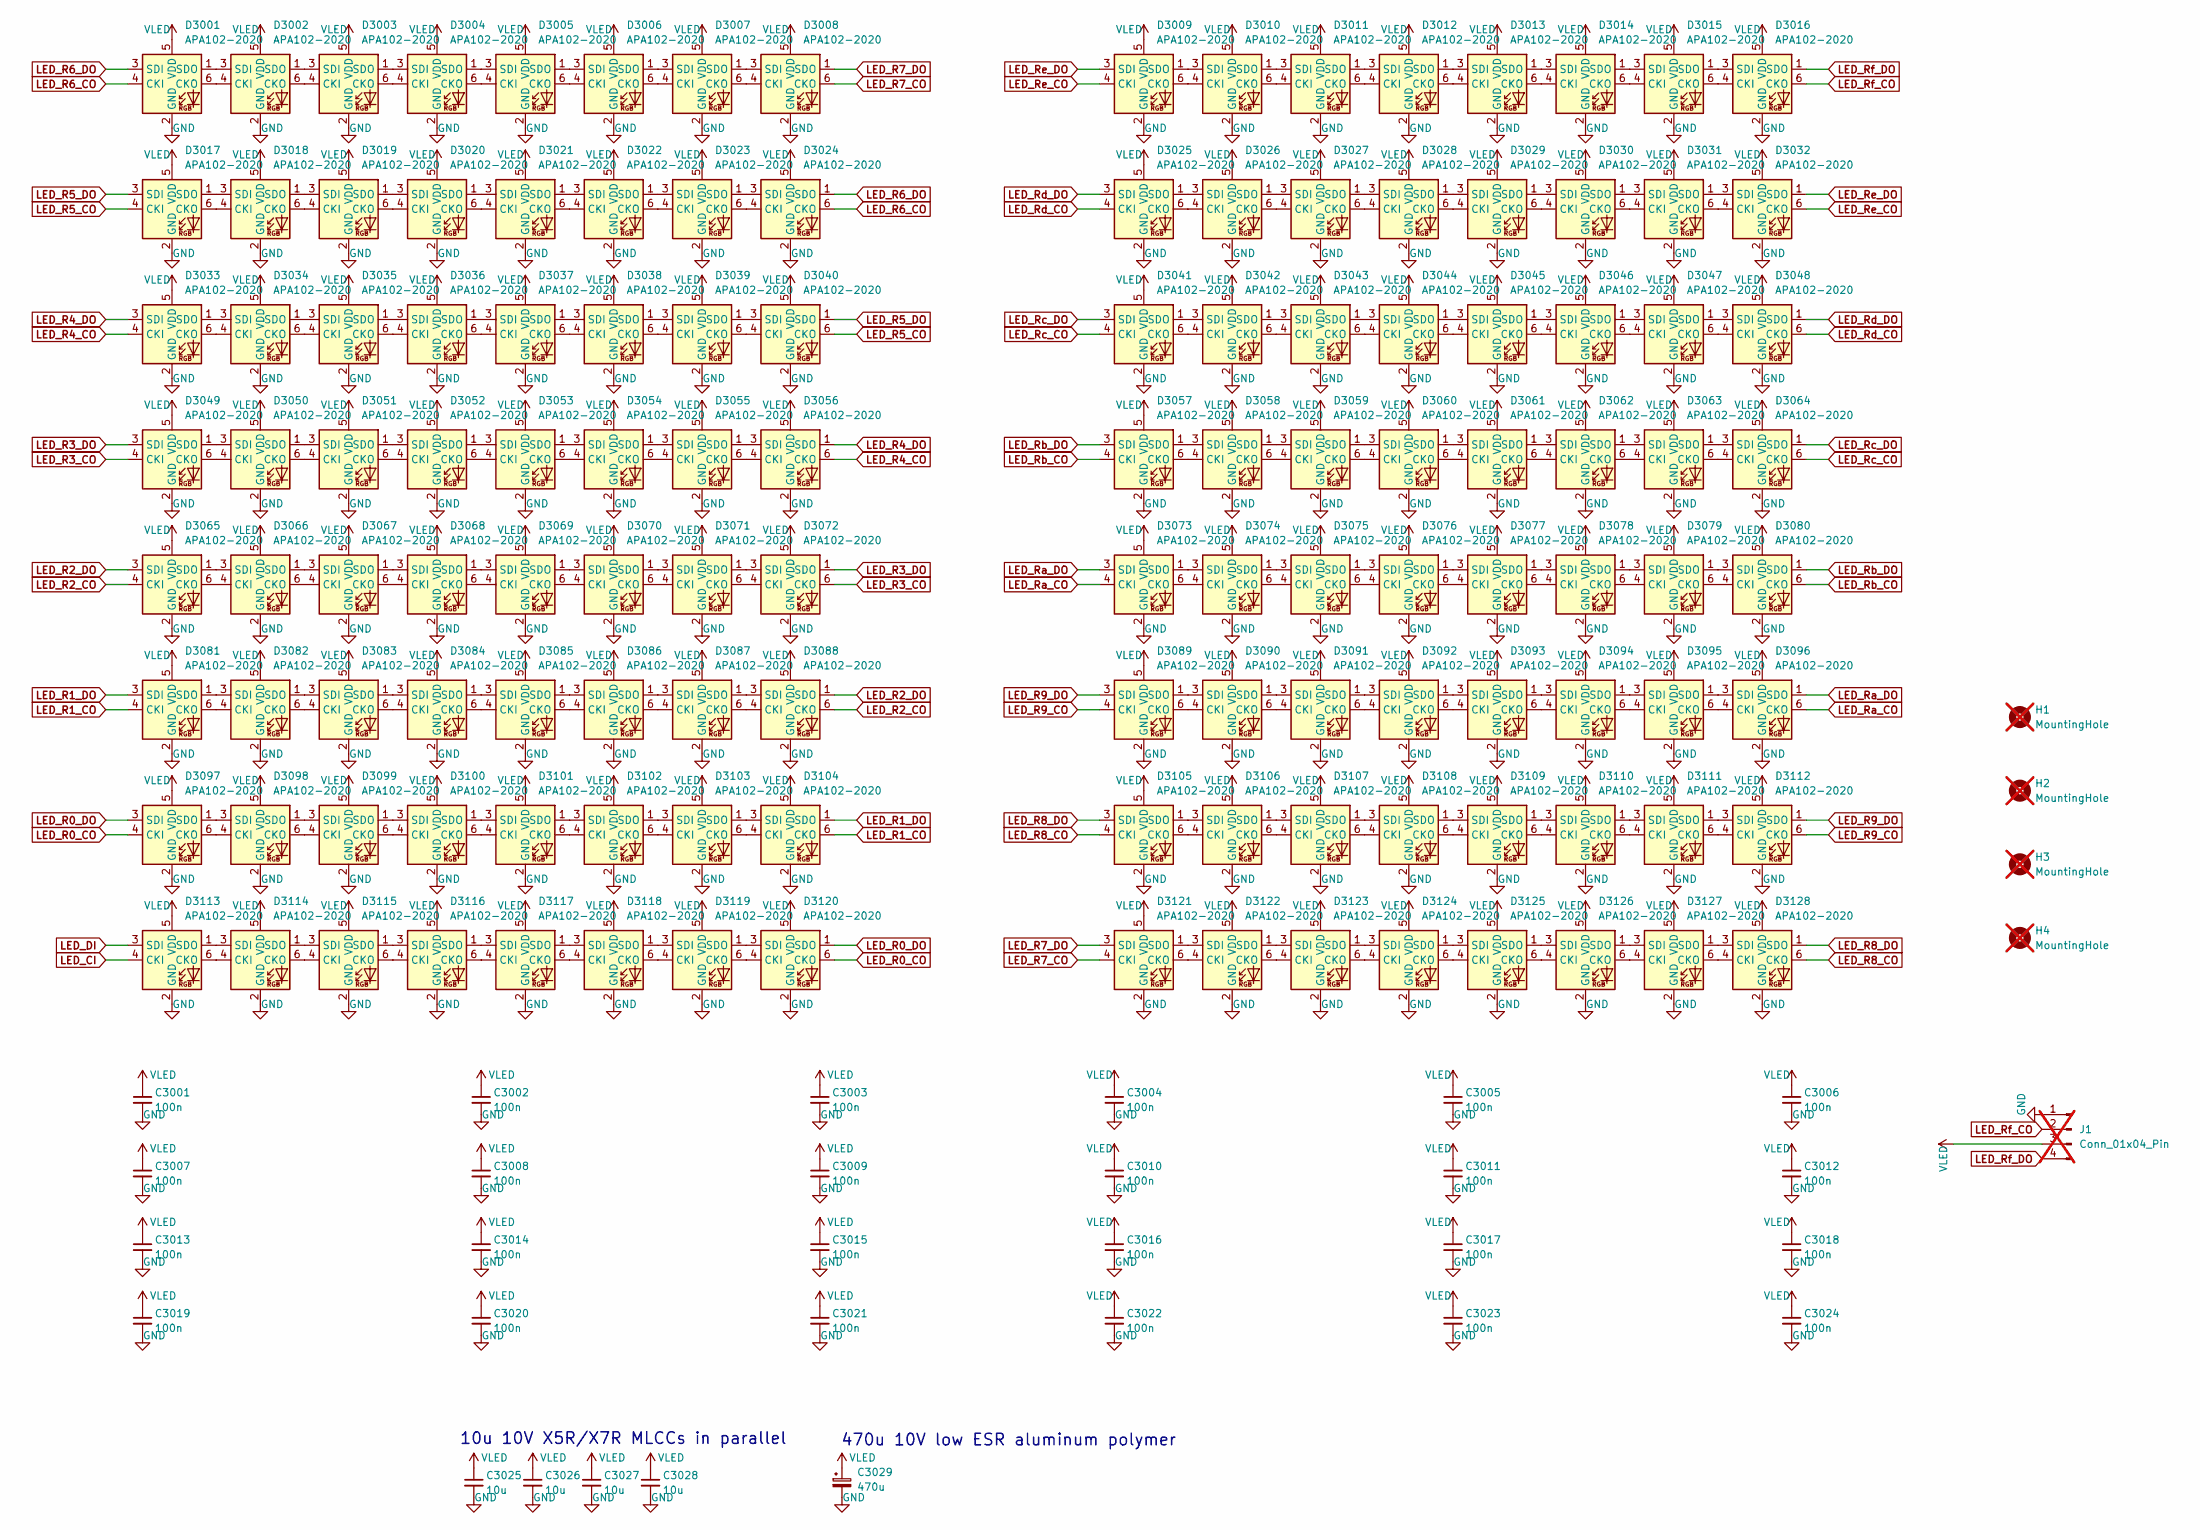
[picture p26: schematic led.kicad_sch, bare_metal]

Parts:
C3001, C3002, C3003, C3004, C3005, C3006, C3007, C3008, C3009, C3010, C3011, C3012, C3013, C3014, C3015, C3016, C3017, C3018, C3019, C3020, C3021, C3022, C3023, C3024: 100n; C_0402_1005Metric
C3025, C3026, C3027, C3028: 10u; C_0603_1608Metric
C3029: 470u; CP_Elec_6.3x7.7
D3001, D3002, D3003, D3004, D3005, D3006, D3007, D3008, D3009, D3010, D3011, D3012, D3013, D3014, D3015, D3016, D3017, D3018, D3019, D3020, D3021, D3022, D3023, D3024, D3025, D3026, D3027, D3028, D3029, D3030, D3031, D3032, D3033, D3034, D3035, D3036, D3037, D3038, D3039, D3040, D3041, D3042, D3043, D3044, D3045, D3046, D3047, D3048, D3049, D3050, D3051, D3052, D3053, D3054, D3055, D3056, D3057, D3058, D3059, D3060, D3061, D3062, D3063, D3064, D3065, D3066, D3067, D3068, D3069, D3070, D3071, D3072, D3073, D3074, D3075, D3076, D3077, D3078, D3079, D3080, D3081, D3082, D3083, D3084, D3085, D3086, D3087, D3088, D3089, D3090, D3091, D3092, D3093, D3094, D3095, D3096, D3097, D3098, D3099, D3100, D3101, D3102, D3103, D3104, D3105, D3106, D3107, D3108, D3109, D3110, D3111, D3112, D3113, D3114, D3115, D3116, D3117, D3118, D3119, D3120, D3121, D3122, D3123, D3124, D3125, D3126, D3127, D3128: APA102-2020; SK9822-EC20
H1, H2, H3, H4: MountingHole; MountingHole_2mm; not fitted
J1: Conn_01x04_Pin; SMD_pads_01x04; not fitted

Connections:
GND: C3001.2, C3002.2, C3003.2, C3004.2, C3005.2, C3006.2, C3007.2, C3008.2, C3009.2, C3010.2, C3011.2, C3012.2, C3013.2, C3014.2, C3015.2, C3016.2, C3017.2, C3018.2, C3019.2, C3020.2, C3021.2, C3022.2, C3023.2, C3024.2, C3025.2, C3026.2, C3027.2, C3028.2, C3029.2, D3001.2 (GND), D3002.2 (GND), D3003.2 (GND), D3004.2 (GND), D3005.2 (GND), D3006.2 (GND), D3007.2 (GND), D3008.2 (GND), D3009.2 (GND), D3010.2 (GND), D3011.2 (GND), D3012.2 (GND), D3013.2 (GND), D3014.2 (GND), D3015.2 (GND), D3016.2 (GND), D3017.2 (GND), D3018.2 (GND), D3019.2 (GND), D3020.2 (GND), D3021.2 (GND), D3022.2 (GND), D3023.2 (GND), D3024.2 (GND), D3025.2 (GND), D3026.2 (GND), D3027.2 (GND), D3028.2 (GND), D3029.2 (GND), D3030.2 (GND), D3031.2 (GND), D3032.2 (GND), D3033.2 (GND), D3034.2 (GND), D3035.2 (GND), D3036.2 (GND), D3037.2 (GND), D3038.2 (GND), D3039.2 (GND), D3040.2 (GND), D3041.2 (GND), D3042.2 (GND), D3043.2 (GND), D3044.2 (GND), D3045.2 (GND), D3046.2 (GND), D3047.2 (GND), D3048.2 (GND), D3049.2 (GND), D3050.2 (GND), D3051.2 (GND), D3052.2 (GND), D3053.2 (GND), D3054.2 (GND), D3055.2 (GND), D3056.2 (GND), D3057.2 (GND), D3058.2 (GND), D3059.2 (GND), D3060.2 (GND), D3061.2 (GND), D3062.2 (GND), D3063.2 (GND), D3064.2 (GND), D3065.2 (GND), D3066.2 (GND), D3067.2 (GND), D3068.2 (GND), D3069.2 (GND), D3070.2 (GND), D3071.2 (GND), D3072.2 (GND), D3073.2 (GND), D3074.2 (GND), D3075.2 (GND), D3076.2 (GND), D3077.2 (GND), D3078.2 (GND), D3079.2 (GND), D3080.2 (GND), D3081.2 (GND), D3082.2 (GND), D3083.2 (GND), D3084.2 (GND), D3085.2 (GND), D3086.2 (GND), D3087.2 (GND), D3088.2 (GND), D3089.2 (GND), D3090.2 (GND), D3091.2 (GND), D3092.2 (GND), D3093.2 (GND), D3094.2 (GND), D3095.2 (GND), D3096.2 (GND), D3097.2 (GND), D3098.2 (GND), D3099.2 (GND), D3100.2 (GND), D3101.2 (GND), D3102.2 (GND), D3103.2 (GND), D3104.2 (GND), D3105.2 (GND), D3106.2 (GND), D3107.2 (GND), D3108.2 (GND), D3109.2 (GND), D3110.2 (GND), D3111.2 (GND), D3112.2 (GND), D3113.2 (GND), D3114.2 (GND), D3115.2 (GND), D3116.2 (GND), D3117.2 (GND), D3118.2 (GND), D3119.2 (GND), D3120.2 (GND), D3121.2 (GND), D3122.2 (GND), D3123.2 (GND), D3124.2 (GND), D3125.2 (GND), D3126.2 (GND), D3127.2 (GND), D3128.2 (GND), J1.1; also elsewhere on the board
LED_CI: D3113.4 (CKI); also elsewhere on the board
LED_DI: D3113.3 (SDI); also elsewhere on the board
LED_R0_CO: D3097.4 (CKI), D3120.6 (CKO)
LED_R0_DO: D3097.3 (SDI), D3120.1 (SDO)
LED_R1_CO: D3081.4 (CKI), D3104.6 (CKO)
LED_R1_DO: D3081.3 (SDI), D3104.1 (SDO)
LED_R2_CO: D3065.4 (CKI), D3088.6 (CKO)
LED_R2_DO: D3065.3 (SDI), D3088.1 (SDO)
LED_R3_CO: D3049.4 (CKI), D3072.6 (CKO)
LED_R3_DO: D3049.3 (SDI), D3072.1 (SDO)
LED_R4_CO: D3033.4 (CKI), D3056.6 (CKO)
LED_R4_DO: D3033.3 (SDI), D3056.1 (SDO)
LED_R5_CO: D3017.4 (CKI), D3040.6 (CKO)
LED_R5_DO: D3017.3 (SDI), D3040.1 (SDO)
LED_R6_CO: D3001.4 (CKI), D3024.6 (CKO)
LED_R6_DO: D3001.3 (SDI), D3024.1 (SDO)
LED_R7_CO: D3008.6 (CKO), D3121.4 (CKI)
LED_R7_DO: D3008.1 (SDO), D3121.3 (SDI)
LED_R8_CO: D3105.4 (CKI), D3128.6 (CKO)
LED_R8_DO: D3105.3 (SDI), D3128.1 (SDO)
LED_R9_CO: D3089.4 (CKI), D3112.6 (CKO)
LED_R9_DO: D3089.3 (SDI), D3112.1 (SDO)
LED_Ra_CO: D3073.4 (CKI), D3096.6 (CKO)
LED_Ra_DO: D3073.3 (SDI), D3096.1 (SDO)
LED_Rb_CO: D3057.4 (CKI), D3080.6 (CKO)
LED_Rb_DO: D3057.3 (SDI), D3080.1 (SDO)
LED_Rc_CO: D3041.4 (CKI), D3064.6 (CKO)
LED_Rc_DO: D3041.3 (SDI), D3064.1 (SDO)
LED_Rd_CO: D3025.4 (CKI), D3048.6 (CKO)
LED_Rd_DO: D3025.3 (SDI), D3048.1 (SDO)
LED_Re_CO: D3009.4 (CKI), D3032.6 (CKO)
LED_Re_DO: D3009.3 (SDI), D3032.1 (SDO)
LED_Rf_CO: D3016.6 (CKO), J1.2
LED_Rf_DO: D3016.1 (SDO), J1.4
unnamed: D3001.6 (CKO), D3002.4 (CKI)
unnamed: D3001.1 (SDO), D3002.3 (SDI)
unnamed: D3002.6 (CKO), D3003.4 (CKI)
unnamed: D3002.1 (SDO), D3003.3 (SDI)
unnamed: D3003.6 (CKO), D3004.4 (CKI)
unnamed: D3003.1 (SDO), D3004.3 (SDI)
unnamed: D3004.6 (CKO), D3005.4 (CKI)
unnamed: D3004.1 (SDO), D3005.3 (SDI)
unnamed: D3005.6 (CKO), D3006.4 (CKI)
unnamed: D3005.1 (SDO), D3006.3 (SDI)
unnamed: D3006.6 (CKO), D3007.4 (CKI)
unnamed: D3006.1 (SDO), D3007.3 (SDI)
unnamed: D3007.6 (CKO), D3008.4 (CKI)
unnamed: D3007.1 (SDO), D3008.3 (SDI)
unnamed: D3009.6 (CKO), D3010.4 (CKI)
unnamed: D3009.1 (SDO), D3010.3 (SDI)
unnamed: D3010.6 (CKO), D3011.4 (CKI)
unnamed: D3010.1 (SDO), D3011.3 (SDI)
unnamed: D3011.6 (CKO), D3012.4 (CKI)
unnamed: D3011.1 (SDO), D3012.3 (SDI)
unnamed: D3012.6 (CKO), D3013.4 (CKI)
unnamed: D3012.1 (SDO), D3013.3 (SDI)
unnamed: D3013.6 (CKO), D3014.4 (CKI)
unnamed: D3013.1 (SDO), D3014.3 (SDI)
unnamed: D3014.6 (CKO), D3015.4 (CKI)
unnamed: D3014.1 (SDO), D3015.3 (SDI)
unnamed: D3015.6 (CKO), D3016.4 (CKI)
unnamed: D3015.1 (SDO), D3016.3 (SDI)
unnamed: D3017.6 (CKO), D3018.4 (CKI)
unnamed: D3017.1 (SDO), D3018.3 (SDI)
unnamed: D3018.6 (CKO), D3019.4 (CKI)
unnamed: D3018.1 (SDO), D3019.3 (SDI)
unnamed: D3019.6 (CKO), D3020.4 (CKI)
unnamed: D3019.1 (SDO), D3020.3 (SDI)
unnamed: D3020.6 (CKO), D3021.4 (CKI)
unnamed: D3020.1 (SDO), D3021.3 (SDI)
unnamed: D3021.6 (CKO), D3022.4 (CKI)
unnamed: D3021.1 (SDO), D3022.3 (SDI)
unnamed: D3022.6 (CKO), D3023.4 (CKI)
unnamed: D3022.1 (SDO), D3023.3 (SDI)
unnamed: D3023.6 (CKO), D3024.4 (CKI)
unnamed: D3023.1 (SDO), D3024.3 (SDI)
unnamed: D3025.6 (CKO), D3026.4 (CKI)
unnamed: D3025.1 (SDO), D3026.3 (SDI)
unnamed: D3026.6 (CKO), D3027.4 (CKI)
unnamed: D3026.1 (SDO), D3027.3 (SDI)
unnamed: D3027.6 (CKO), D3028.4 (CKI)
unnamed: D3027.1 (SDO), D3028.3 (SDI)
unnamed: D3028.6 (CKO), D3029.4 (CKI)
unnamed: D3028.1 (SDO), D3029.3 (SDI)
unnamed: D3029.6 (CKO), D3030.4 (CKI)
unnamed: D3029.1 (SDO), D3030.3 (SDI)
unnamed: D3030.6 (CKO), D3031.4 (CKI)
unnamed: D3030.1 (SDO), D3031.3 (SDI)
unnamed: D3031.6 (CKO), D3032.4 (CKI)
unnamed: D3031.1 (SDO), D3032.3 (SDI)
unnamed: D3033.6 (CKO), D3034.4 (CKI)
unnamed: D3033.1 (SDO), D3034.3 (SDI)
unnamed: D3034.6 (CKO), D3035.4 (CKI)
unnamed: D3034.1 (SDO), D3035.3 (SDI)
unnamed: D3035.6 (CKO), D3036.4 (CKI)
unnamed: D3035.1 (SDO), D3036.3 (SDI)
unnamed: D3036.6 (CKO), D3037.4 (CKI)
unnamed: D3036.1 (SDO), D3037.3 (SDI)
unnamed: D3037.6 (CKO), D3038.4 (CKI)
unnamed: D3037.1 (SDO), D3038.3 (SDI)
unnamed: D3038.6 (CKO), D3039.4 (CKI)
unnamed: D3038.1 (SDO), D3039.3 (SDI)
unnamed: D3039.6 (CKO), D3040.4 (CKI)
unnamed: D3039.1 (SDO), D3040.3 (SDI)
unnamed: D3041.6 (CKO), D3042.4 (CKI)
unnamed: D3041.1 (SDO), D3042.3 (SDI)
unnamed: D3042.6 (CKO), D3043.4 (CKI)
unnamed: D3042.1 (SDO), D3043.3 (SDI)
unnamed: D3043.6 (CKO), D3044.4 (CKI)
unnamed: D3043.1 (SDO), D3044.3 (SDI)
unnamed: D3044.6 (CKO), D3045.4 (CKI)
unnamed: D3044.1 (SDO), D3045.3 (SDI)
unnamed: D3045.6 (CKO), D3046.4 (CKI)
unnamed: D3045.1 (SDO), D3046.3 (SDI)
unnamed: D3046.6 (CKO), D3047.4 (CKI)
unnamed: D3046.1 (SDO), D3047.3 (SDI)
unnamed: D3047.6 (CKO), D3048.4 (CKI)
unnamed: D3047.1 (SDO), D3048.3 (SDI)
unnamed: D3049.6 (CKO), D3050.4 (CKI)
unnamed: D3049.1 (SDO), D3050.3 (SDI)
unnamed: D3050.6 (CKO), D3051.4 (CKI)
unnamed: D3050.1 (SDO), D3051.3 (SDI)
unnamed: D3051.6 (CKO), D3052.4 (CKI)
unnamed: D3051.1 (SDO), D3052.3 (SDI)
unnamed: D3052.6 (CKO), D3053.4 (CKI)
unnamed: D3052.1 (SDO), D3053.3 (SDI)
unnamed: D3053.6 (CKO), D3054.4 (CKI)
unnamed: D3053.1 (SDO), D3054.3 (SDI)
unnamed: D3054.6 (CKO), D3055.4 (CKI)
unnamed: D3054.1 (SDO), D3055.3 (SDI)
unnamed: D3055.6 (CKO), D3056.4 (CKI)
unnamed: D3055.1 (SDO), D3056.3 (SDI)
unnamed: D3057.6 (CKO), D3058.4 (CKI)
unnamed: D3057.1 (SDO), D3058.3 (SDI)
unnamed: D3058.6 (CKO), D3059.4 (CKI)
unnamed: D3058.1 (SDO), D3059.3 (SDI)
unnamed: D3059.6 (CKO), D3060.4 (CKI)
unnamed: D3059.1 (SDO), D3060.3 (SDI)
unnamed: D3060.6 (CKO), D3061.4 (CKI)
unnamed: D3060.1 (SDO), D3061.3 (SDI)
unnamed: D3061.6 (CKO), D3062.4 (CKI)
unnamed: D3061.1 (SDO), D3062.3 (SDI)
unnamed: D3062.6 (CKO), D3063.4 (CKI)
unnamed: D3062.1 (SDO), D3063.3 (SDI)
unnamed: D3063.6 (CKO), D3064.4 (CKI)
unnamed: D3063.1 (SDO), D3064.3 (SDI)
unnamed: D3065.6 (CKO), D3066.4 (CKI)
unnamed: D3065.1 (SDO), D3066.3 (SDI)
unnamed: D3066.6 (CKO), D3067.4 (CKI)
unnamed: D3066.1 (SDO), D3067.3 (SDI)
unnamed: D3067.6 (CKO), D3068.4 (CKI)
unnamed: D3067.1 (SDO), D3068.3 (SDI)
unnamed: D3068.6 (CKO), D3069.4 (CKI)
unnamed: D3068.1 (SDO), D3069.3 (SDI)
unnamed: D3069.6 (CKO), D3070.4 (CKI)
unnamed: D3069.1 (SDO), D3070.3 (SDI)
unnamed: D3070.6 (CKO), D3071.4 (CKI)
unnamed: D3070.1 (SDO), D3071.3 (SDI)
unnamed: D3071.6 (CKO), D3072.4 (CKI)
unnamed: D3071.1 (SDO), D3072.3 (SDI)
unnamed: D3073.6 (CKO), D3074.4 (CKI)
unnamed: D3073.1 (SDO), D3074.3 (SDI)
unnamed: D3074.6 (CKO), D3075.4 (CKI)
unnamed: D3074.1 (SDO), D3075.3 (SDI)
unnamed: D3075.6 (CKO), D3076.4 (CKI)
unnamed: D3075.1 (SDO), D3076.3 (SDI)
unnamed: D3076.6 (CKO), D3077.4 (CKI)
unnamed: D3076.1 (SDO), D3077.3 (SDI)
unnamed: D3077.6 (CKO), D3078.4 (CKI)
unnamed: D3077.1 (SDO), D3078.3 (SDI)
unnamed: D3078.6 (CKO), D3079.4 (CKI)
unnamed: D3078.1 (SDO), D3079.3 (SDI)
unnamed: D3079.6 (CKO), D3080.4 (CKI)
unnamed: D3079.1 (SDO), D3080.3 (SDI)
unnamed: D3081.6 (CKO), D3082.4 (CKI)
unnamed: D3081.1 (SDO), D3082.3 (SDI)
unnamed: D3082.6 (CKO), D3083.4 (CKI)
unnamed: D3082.1 (SDO), D3083.3 (SDI)
unnamed: D3083.6 (CKO), D3084.4 (CKI)
unnamed: D3083.1 (SDO), D3084.3 (SDI)
unnamed: D3084.6 (CKO), D3085.4 (CKI)
unnamed: D3084.1 (SDO), D3085.3 (SDI)
unnamed: D3085.6 (CKO), D3086.4 (CKI)
unnamed: D3085.1 (SDO), D3086.3 (SDI)
unnamed: D3086.6 (CKO), D3087.4 (CKI)
unnamed: D3086.1 (SDO), D3087.3 (SDI)
unnamed: D3087.6 (CKO), D3088.4 (CKI)
unnamed: D3087.1 (SDO), D3088.3 (SDI)
unnamed: D3089.6 (CKO), D3090.4 (CKI)
unnamed: D3089.1 (SDO), D3090.3 (SDI)
unnamed: D3090.6 (CKO), D3091.4 (CKI)
unnamed: D3090.1 (SDO), D3091.3 (SDI)
unnamed: D3091.6 (CKO), D3092.4 (CKI)
unnamed: D3091.1 (SDO), D3092.3 (SDI)
unnamed: D3092.6 (CKO), D3093.4 (CKI)
unnamed: D3092.1 (SDO), D3093.3 (SDI)
unnamed: D3093.6 (CKO), D3094.4 (CKI)
unnamed: D3093.1 (SDO), D3094.3 (SDI)
unnamed: D3094.6 (CKO), D3095.4 (CKI)
unnamed: D3094.1 (SDO), D3095.3 (SDI)
unnamed: D3095.6 (CKO), D3096.4 (CKI)
unnamed: D3095.1 (SDO), D3096.3 (SDI)
unnamed: D3097.6 (CKO), D3098.4 (CKI)
unnamed: D3097.1 (SDO), D3098.3 (SDI)
unnamed: D3098.6 (CKO), D3099.4 (CKI)
unnamed: D3098.1 (SDO), D3099.3 (SDI)
unnamed: D3099.6 (CKO), D3100.4 (CKI)
unnamed: D3099.1 (SDO), D3100.3 (SDI)
unnamed: D3100.6 (CKO), D3101.4 (CKI)
unnamed: D3100.1 (SDO), D3101.3 (SDI)
unnamed: D3101.6 (CKO), D3102.4 (CKI)
unnamed: D3101.1 (SDO), D3102.3 (SDI)
unnamed: D3102.6 (CKO), D3103.4 (CKI)
unnamed: D3102.1 (SDO), D3103.3 (SDI)
unnamed: D3103.6 (CKO), D3104.4 (CKI)
unnamed: D3103.1 (SDO), D3104.3 (SDI)
unnamed: D3105.6 (CKO), D3106.4 (CKI)
unnamed: D3105.1 (SDO), D3106.3 (SDI)
unnamed: D3106.6 (CKO), D3107.4 (CKI)
unnamed: D3106.1 (SDO), D3107.3 (SDI)
unnamed: D3107.6 (CKO), D3108.4 (CKI)
unnamed: D3107.1 (SDO), D3108.3 (SDI)
unnamed: D3108.6 (CKO), D3109.4 (CKI)
unnamed: D3108.1 (SDO), D3109.3 (SDI)
unnamed: D3109.6 (CKO), D3110.4 (CKI)
unnamed: D3109.1 (SDO), D3110.3 (SDI)
unnamed: D3110.6 (CKO), D3111.4 (CKI)
unnamed: D3110.1 (SDO), D3111.3 (SDI)
unnamed: D3111.6 (CKO), D3112.4 (CKI)
unnamed: D3111.1 (SDO), D3112.3 (SDI)
unnamed: D3113.6 (CKO), D3114.4 (CKI)
unnamed: D3113.1 (SDO), D3114.3 (SDI)
unnamed: D3114.6 (CKO), D3115.4 (CKI)
unnamed: D3114.1 (SDO), D3115.3 (SDI)
unnamed: D3115.6 (CKO), D3116.4 (CKI)
unnamed: D3115.1 (SDO), D3116.3 (SDI)
unnamed: D3116.6 (CKO), D3117.4 (CKI)
unnamed: D3116.1 (SDO), D3117.3 (SDI)
unnamed: D3117.6 (CKO), D3118.4 (CKI)
unnamed: D3117.1 (SDO), D3118.3 (SDI)
unnamed: D3118.6 (CKO), D3119.4 (CKI)
unnamed: D3118.1 (SDO), D3119.3 (SDI)
unnamed: D3119.6 (CKO), D3120.4 (CKI)
unnamed: D3119.1 (SDO), D3120.3 (SDI)
unnamed: D3121.6 (CKO), D3122.4 (CKI)
unnamed: D3121.1 (SDO), D3122.3 (SDI)
unnamed: D3122.6 (CKO), D3123.4 (CKI)
unnamed: D3122.1 (SDO), D3123.3 (SDI)
unnamed: D3123.6 (CKO), D3124.4 (CKI)
unnamed: D3123.1 (SDO), D3124.3 (SDI)
unnamed: D3124.6 (CKO), D3125.4 (CKI)
unnamed: D3124.1 (SDO), D3125.3 (SDI)
unnamed: D3125.6 (CKO), D3126.4 (CKI)
unnamed: D3125.1 (SDO), D3126.3 (SDI)
unnamed: D3126.6 (CKO), D3127.4 (CKI)
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

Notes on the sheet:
10u 10V X5R/X7R MLCCs in parallel
470u 10V low ESR aluminum polymer

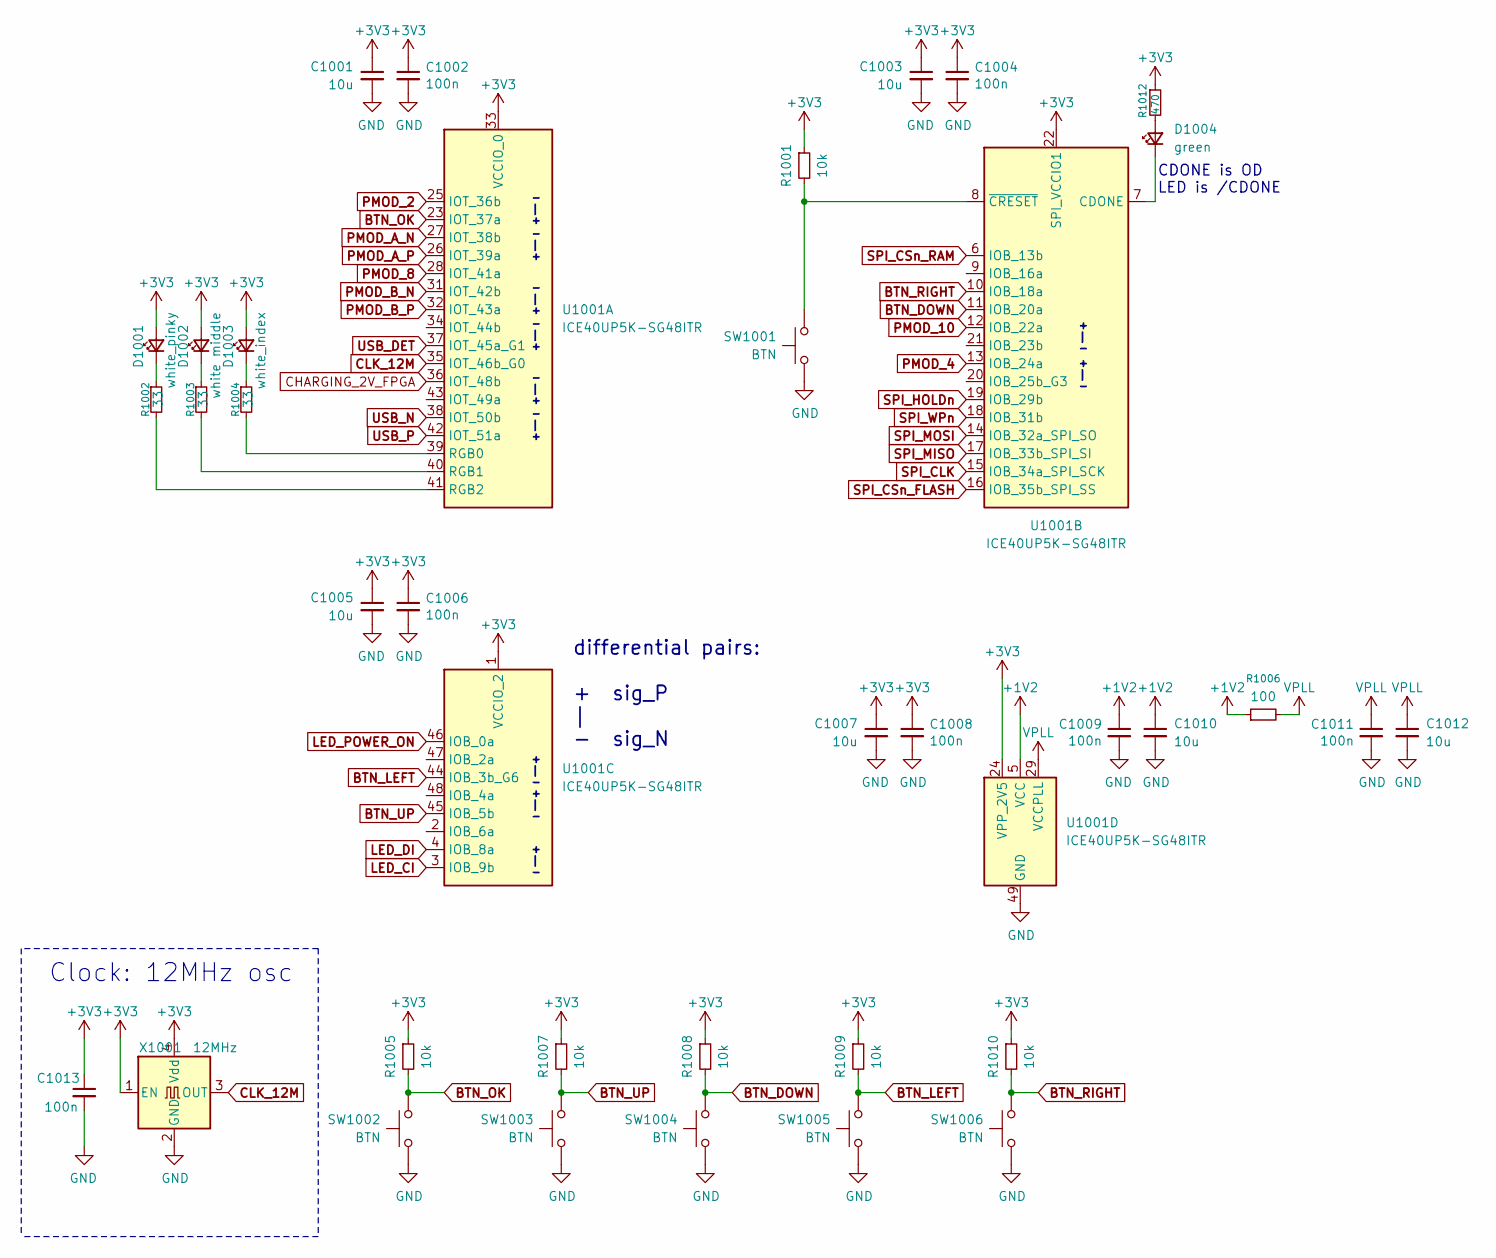
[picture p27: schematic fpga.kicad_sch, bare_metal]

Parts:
C1001, C1003, C1005, C1007, C1010, C1012: 10u; C_0603_1608Metric
C1002, C1004, C1006, C1008, C1009, C1011, C1013: 100n; C_0402_1005Metric
D1001: white_pinky; LED_0805_2012Metric
D1002: white middle; LED_0805_2012Metric
D1003: white_index; LED_0805_2012Metric
D1004: green; LED_0805_2012Metric
R1001, R1005, R1007, R1008, R1009, R1010: 10k; R_0402_1005Metric
R1002, R1003, R1004: 33; R_0402_1005Metric
R1006: 100; R_0402_1005Metric
R1012: 470; R_0402_1005Metric
SW1001, SW1002, SW1003, SW1004, SW1005, SW1006: BTN; SW_Push_1P1T_XKB_TS-1187A
U1001: ICE40UP5K-SG48ITR; QFN-48-1EP_7x7mm_P0.5mm_EP5.6x5.6mm
X1001: 12MHz; Crystal_SMD_3225-4Pin_3.2x2.5mm

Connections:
+1V2: C1009.1, C1010.1, R1006.1, U1001.5 (VCC), U1001.30 (VCC); also elsewhere on the board
+3V3: C1001.1, C1002.1, C1003.1, C1004.1, C1005.1, C1006.1, C1007.1, C1008.1, C1013.1, D1001.2 (A), D1002.2 (A), D1003.2 (A), R1001.1, R1005.1, R1007.1, R1008.1, R1009.1, R1010.1, R1012.1, U1001.1 (VCCIO_2), U1001.22 (SPI_VCCIO1), U1001.24 (VPP_2V5), U1001.33 (VCCIO_0), X1001.1 (EN), X1001.4 (Vdd); also elsewhere on the board
BTN_DOWN: R1008.2, SW1004.1, U1001.11 (IOB_20a)
BTN_LEFT: R1009.2, SW1005.1, U1001.44 (IOB_3b_G6)
BTN_OK: R1005.2, SW1002.1, U1001.23 (IOT_37a)
BTN_RIGHT: R1010.2, SW1006.1, U1001.10 (IOB_18a)
BTN_UP: R1007.2, SW1003.1, U1001.45 (IOB_5b)
CHARGING_2V_FPGA: U1001.36 (IOT_48b); also elsewhere on the board
CLK_12M: U1001.35 (IOT_46b_G0), X1001.3 (OUT)
GND: C1001.2, C1002.2, C1003.2, C1004.2, C1005.2, C1006.2, C1007.2, C1008.2, C1009.2, C1010.2, C1011.2, C1012.2, C1013.2, SW1001.2, SW1002.2, SW1003.2, SW1004.2, SW1005.2, SW1006.2, U1001.49 (GND), X1001.2 (GND); also elsewhere on the board
LED_CI: U1001.3 (IOB_9b); also elsewhere on the board
LED_DI: U1001.4 (IOB_8a); also elsewhere on the board
LED_POWER_ON: U1001.46 (IOB_0a); also elsewhere on the board
unnamed: D1001.1 (K), R1002.1
unnamed: D1002.1 (K), R1003.1
unnamed: D1003.1 (K), R1004.1
unnamed: D1004.2 (A), R1012.2
unnamed: D1004.1 (K), U1001.7 (CDONE)
unnamed: R1004.2, U1001.39 (RGB0)
unnamed: R1003.2, U1001.40 (RGB1)
unnamed: R1002.2, U1001.41 (RGB2)
unnamed: R1001.2, SW1001.1, U1001.8 (~CRESET)
PMOD_2: U1001.25 (IOT_36b); also elsewhere on the board
PMOD_4: U1001.13 (IOB_24a); also elsewhere on the board
PMOD_8: U1001.28 (IOT_41a); also elsewhere on the board
PMOD_10: U1001.12 (IOB_22a); also elsewhere on the board
PMOD_A_N: U1001.27 (IOT_38b); also elsewhere on the board
PMOD_A_P: U1001.26 (IOT_39a); also elsewhere on the board
PMOD_B_N: U1001.31 (IOT_42b); also elsewhere on the board
PMOD_B_P: U1001.32 (IOT_43a); also elsewhere on the board
SPI_CLK: U1001.15 (IOB_34a_SPI_SCK); also elsewhere on the board
SPI_CSn_FLASH: U1001.16 (IOB_35b_SPI_SS); also elsewhere on the board
SPI_CSn_RAM: U1001.6 (IOB_13b); also elsewhere on the board
SPI_HOLDn: U1001.19 (IOB_29b); also elsewhere on the board
SPI_MISO: U1001.17 (IOB_33b_SPI_SI); also elsewhere on the board
SPI_MOSI: U1001.14 (IOB_32a_SPI_SO); also elsewhere on the board
SPI_WPn: U1001.18 (IOB_31b); also elsewhere on the board
USB_DET: U1001.37 (IOT_45a_G1); also elsewhere on the board
USB_N: U1001.38 (IOT_50b); also elsewhere on the board
USB_P: U1001.42 (IOT_51a); also elsewhere on the board
VPLL: C1011.1, C1012.1, R1006.2, U1001.29 (VCCPLL)

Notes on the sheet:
+ | -
- | +
differential pairs: + sig_P | - sig_N
Clock: 12MHz osc
CDONE is OD LED is /CDONE

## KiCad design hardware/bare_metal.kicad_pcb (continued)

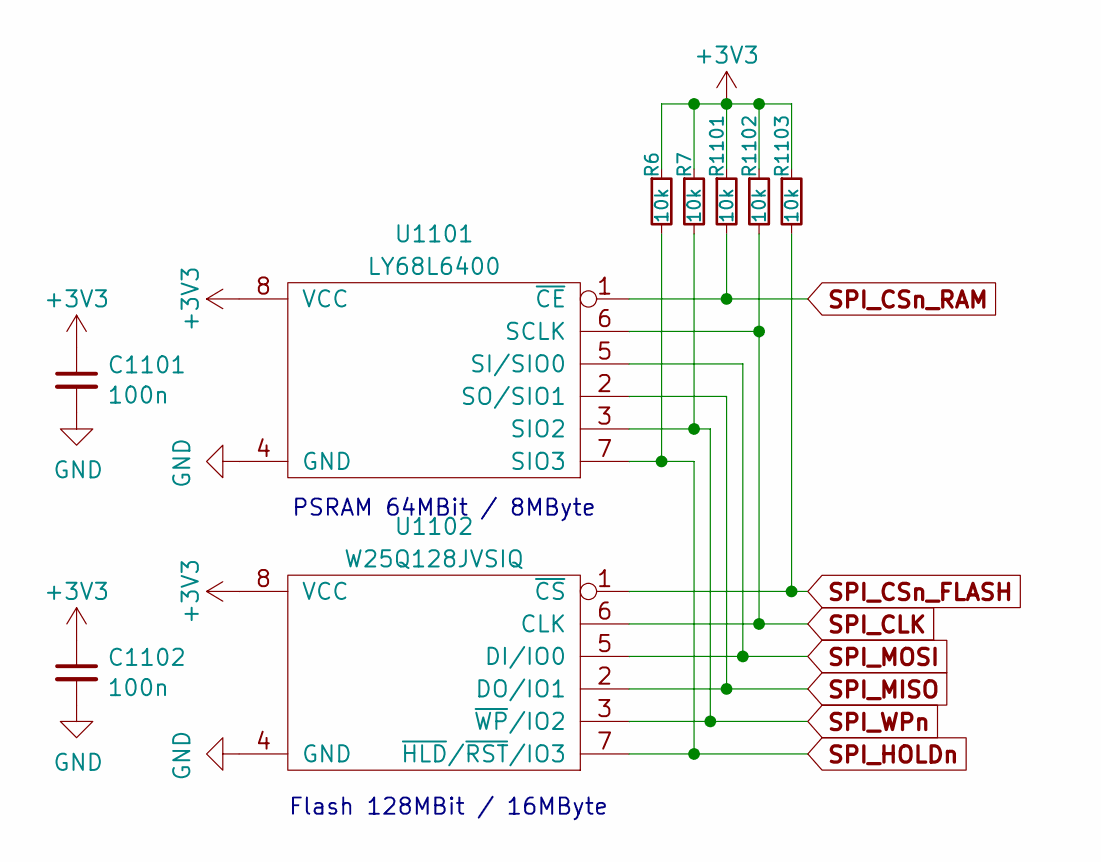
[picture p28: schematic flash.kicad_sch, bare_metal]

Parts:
C1101, C1102: 100n; C_0402_1005Metric
R6, R7, R1101, R1102, R1103: 10k; R_0402_1005Metric
U1101: LY68L6400; SOIC-8_3.9x4.9mm_P1.27mm
U1102: W25Q128JVSIQ; SOIC-8_5.3x5.3mm_P1.27mm

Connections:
+3V3: C1101.1, C1102.1, R6.1, R7.1, R1101.1, R1102.1, R1103.1, U1101.8 (VCC), U1102.8 (VCC); also elsewhere on the board
GND: C1101.2, C1102.2, U1101.4 (GND), U1102.4 (GND); also elsewhere on the board
SPI_CLK: R1102.2, U1101.6 (SCLK), U1102.6 (CLK); also elsewhere on the board
SPI_CSn_FLASH: R1103.2, U1102.1 (~CS); also elsewhere on the board
SPI_CSn_RAM: R1101.2, U1101.1 (~CE); also elsewhere on the board
SPI_HOLDn: R6.2, U1101.7 (SIO3), U1102.7 (~HLD/~RST/IO3); also elsewhere on the board
SPI_MISO: U1101.2 (SO/SIO1), U1102.2 (DO/IO1); also elsewhere on the board
SPI_MOSI: U1101.5 (SI/SIO0), U1102.5 (DI/IO0); also elsewhere on the board
SPI_WPn: R7.2, U1101.3 (SIO2), U1102.3 (~WP/IO2); also elsewhere on the board

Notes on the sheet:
PSRAM 64MBit / 8MByte
Flash 128MBit / 16MByte

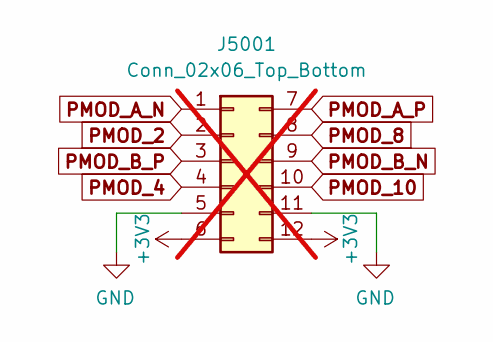
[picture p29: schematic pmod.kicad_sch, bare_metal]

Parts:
J5001: Conn_02x06_Top_Bottom; PMOD_PinSocket_2x06_P2.54mm_Horizontal; not fitted

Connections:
+3V3: J5001.6, J5001.12; also elsewhere on the board
GND: J5001.5, J5001.11; also elsewhere on the board
PMOD_2: J5001.2; also elsewhere on the board
PMOD_4: J5001.4; also elsewhere on the board
PMOD_8: J5001.8; also elsewhere on the board
PMOD_10: J5001.10; also elsewhere on the board
PMOD_A_N: J5001.1; also elsewhere on the board
PMOD_A_P: J5001.7; also elsewhere on the board
PMOD_B_N: J5001.9; also elsewhere on the board
PMOD_B_P: J5001.3; also elsewhere on the board

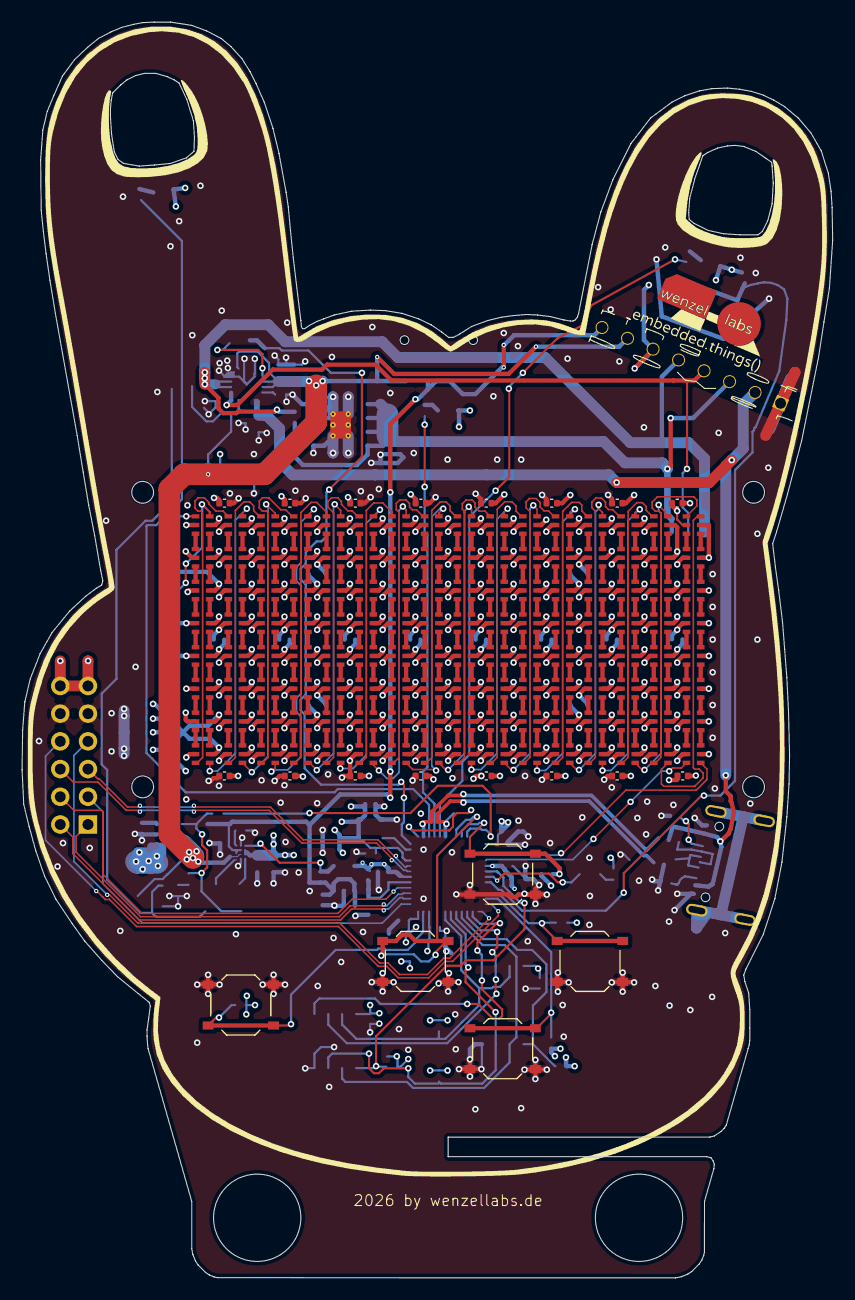
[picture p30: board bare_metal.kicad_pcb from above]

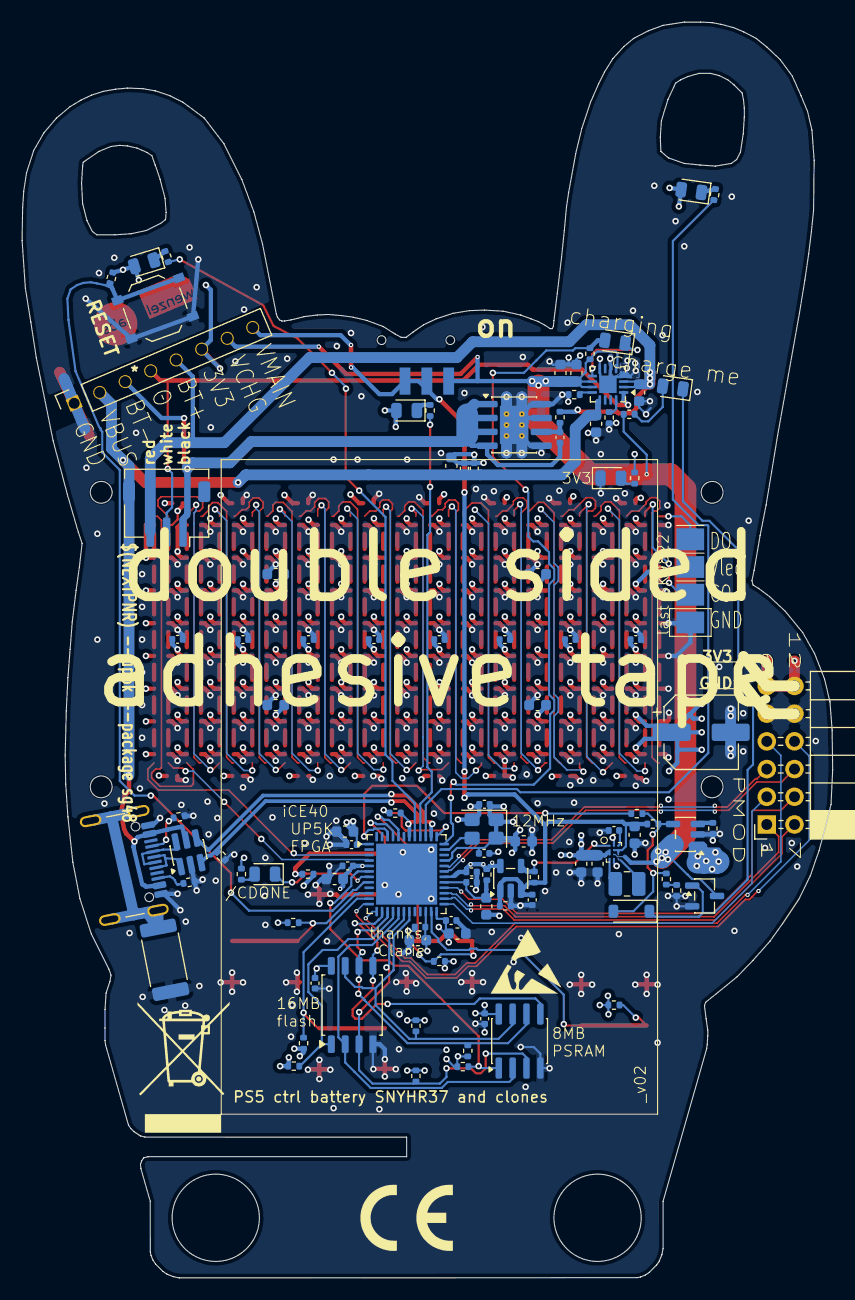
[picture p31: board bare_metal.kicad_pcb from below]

Board: 4 copper layers, 74.3 x 115.1 mm, 257 parts (103 on the bottom side), 323 nets.

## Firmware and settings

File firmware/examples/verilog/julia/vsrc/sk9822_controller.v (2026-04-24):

module sk9822_controller(    input  wire clk,    input  wire rst,
    // Write parameters
    input  wire [3:0] wr_x,
    input  wire [3:0] wr_y,
    input  wire [7:0] wr_r,
    input  wire [7:0] wr_g,
    input  wire [7:0] wr_b,
    input  wire       wr_en,

    // Hardware outputs (SPI-ish)
    output reg led_data,
    output reg led_clk
);

    // -- Framebuffer Memory --
    // 16 cols (x) x 8 rows (y) = 128 LEDs.
    reg [7:0] mem_r [0:127];
    reg [7:0] mem_g [0:127];
    reg [7:0] mem_b [0:127];
    
    // Mapping: X=0..15, Y=0..7 -> index = (15 - wr_x) * 8 + wr_y
    wire [6:0] wr_addr = ((7'd15 - wr_x) * 8) + wr_y; // Safe math

    always @(posedge clk) begin
        if (wr_en) begin
            mem_r[wr_addr] <= wr_r;
            mem_g[wr_addr] <= wr_g;
            mem_b[wr_addr] <= wr_b;
        end
    end

    reg [2:0]  clk_div = 0;
    reg [12:0] bit_counter = 0;
    initial begin
        led_clk = 0;
        led_data = 0;
    end

    wire tick = (clk_div == 3'h0);
    wire next_bit = tick && !led_clk;

    // Prefetch for memory reads
    wire [6:0] led_index = (bit_counter >= 32) ? ((bit_counter - 32) >> 5) : 0;
    reg [7:0] red, green, blue;

    always @(posedge clk) begin
        red   <= mem_r[led_index];
        green <= mem_g[led_index];
        blue  <= mem_b[led_index];
    end

    // APA102 / SK9822 format: 111, brightness, then B, G, R
    wire [31:0] current_frame = {3'b111, 5'h01, blue, green, red};

    always @(posedge clk) begin
        if (rst) begin
            clk_div     <= 0;
            led_clk     <= 0;
            led_data    <= 0;
            bit_counter <= 0;
        end else begin
            clk_div <= clk_div + 1;
            
            if (tick) begin
                led_clk <= ~led_clk;
                
                if (led_clk) begin // Update on falling edge of led_clk
                    // On falling edge of generated led_clk, we push new data
                    
                    if (bit_counter < 32) begin
                        // 32 bits Start Frame
                        led_data <= 1'b0;
                    end else if (bit_counter < 4128) begin // 32 + (128 LEDs * 32 bits)
                        // MSB first
                        led_data <= current_frame[~bit_counter[4:0]];
                    end else begin
                        // End Frame (at least 64 bits of 1s or 0s to latch)
                        led_data <= 1'b1;
                    end

                    // Count bits
                    if (bit_counter == 13'h105F) begin // 4128 + 64 - 1
                        bit_counter <= 0;
                    end else begin
                        bit_counter <= bit_counter + 1;
                    end
                end
            end
        end
    end

endmodule

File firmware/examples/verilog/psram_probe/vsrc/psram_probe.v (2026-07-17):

module psram_probe(
    input clk,
    input rst,
    input restart,  // Pulse to restart test
    output reg spi_mosi,
    input spi_miso,
    output reg spi_clk,
    output reg spi_csn,
    output reg busy,
    output reg [31:0] detected_bytes,
    output reg [7:0] state,
    output [23:0] addr_out,
    output reg test_passed  // High if test passed (all bytes matched)
);
    reg clk_div;
    localparam S_START_WRITE = 0;
    localparam S_CMD_WRITE = 1;
    localparam S_ADDR_WRITE = 2;
    localparam S_DATA_WRITE = 3;
    localparam S_FINISH_WRITE = 4;
    localparam S_START_READ = 5;
    localparam S_CMD_READ = 6;
    localparam S_ADDR_READ = 7;
    localparam S_DATA_READ = 8;
    localparam S_FINISH_READ = 9;
    localparam S_CHECK = 10;
    localparam S_DONE = 11;
    localparam S_WAIT = 12;

    reg [7:0] bitcnt;
    reg [7:0] cmd_byte;
    reg [23:0] addr;
    reg [7:0] in_byte;
    reg [7:0] next_state;
    reg spi_phase;
    reg [7:0] test_pattern;

    // Export addr for live progress updates
    assign addr_out = addr;

    localparam S_INIT_66_CMD = 20;
    localparam S_INIT_66_CS_HIGH = 21;
    localparam S_INIT_99_CMD = 22;
    localparam S_INIT_99_CS_HIGH = 23;

    initial begin
        spi_mosi = 1'b0;
        spi_clk = 1'b0;
        spi_csn = 1'b1;
        busy = 1'b1;
        detected_bytes = 32'd0;
        clk_div = 1'b0;
        state = S_INIT_66_CMD;
        addr = 24'h000000;
        test_pattern = 8'hA5;
        spi_phase = 0;
        test_passed = 1'b1;
    end

    always @(posedge clk) begin
        if (rst) begin
            state <= S_INIT_66_CMD;
            spi_csn <= 1'b1;
            busy <= 1'b1;
            detected_bytes <= 32'd0;
            clk_div <= 0;
            addr <= 0;
            test_passed <= 1'b1;
        end else if (restart && state == S_DONE) begin
            // Restart the test from beginning
            state <= S_INIT_66_CMD;
            addr <= 0;
            detected_bytes <= 0;
            test_passed <= 1'b1;
        end else begin
            clk_div <= ~clk_div;
            if (!clk_div) begin
                case (state)

                    S_INIT_66_CMD: begin
                        spi_csn <= 1'b0;
                        cmd_byte <= 8'h66; // RESET ENABLE
                        bitcnt <= 8'd7;
                        spi_phase <= 1'b0;
                        next_state <= S_INIT_66_CS_HIGH;
                        state <= S_CMD_WRITE;
                    end
                    S_INIT_66_CS_HIGH: begin
                        spi_clk <= 1'b0;
                        spi_csn <= 1'b1;
                        bitcnt <= 8'd50; // wait some cycles
                        next_state <= S_INIT_99_CMD;
                        state <= S_WAIT;
                    end
                    S_INIT_99_CMD: begin
                        spi_csn <= 1'b0;
                        cmd_byte <= 8'h99; // RESET
                        bitcnt <= 8'd7;
                        spi_phase <= 1'b0;
                        next_state <= S_INIT_99_CS_HIGH;
                        state <= S_CMD_WRITE;
                    end
                    S_INIT_99_CS_HIGH: begin
                        spi_clk <= 1'b0;
                        spi_csn <= 1'b1;
                        bitcnt <= 8'd200; // wait 200 cycles, ~10+ us
                        next_state <= S_START_WRITE;
                        state <= S_WAIT;
                    end
                    S_START_WRITE: begin
                        spi_csn <= 1'b0;
                        cmd_byte <= 8'h02; // WRITE
                        bitcnt <= 8'd7;
                        spi_phase <= 1'b0;
                        // Vary the pattern per address to avoid false wrap matches on a floating bus
                        test_pattern <= 8'hA5 + addr[23:16];
                        state <= S_CMD_WRITE;
                    end
                    S_CMD_WRITE: begin
                        if (spi_phase == 1'b0) begin
                            spi_mosi <= cmd_byte[bitcnt];
                            spi_clk <= 1'b0;
                            spi_phase <= 1'b1;
                        end else begin
                            spi_clk <= 1'b1;
                            spi_phase <= 1'b0;
                            if (bitcnt == 0) begin
                                if (state == S_CMD_WRITE && (cmd_byte == 8'h66 || cmd_byte == 8'h99)) begin
                                    state <= next_state;
                                end else begin
                                    bitcnt <= 8'd23;
                                    state <= S_ADDR_WRITE;
                                end
                            end else begin
                                bitcnt <= bitcnt - 1;
                            end
                        end
                    end
                    S_ADDR_WRITE: begin
                        if (spi_phase == 1'b0) begin
                            spi_mosi <= addr[bitcnt];
                            spi_clk <= 1'b0;
                            spi_phase <= 1'b1;
                        end else begin
                            spi_clk <= 1'b1;
                            spi_phase <= 1'b0;
                            if (bitcnt == 0) begin
                                bitcnt <= 8'd7;
                                state <= S_DATA_WRITE;
                            end else begin
                                bitcnt <= bitcnt - 1;
                            end
                        end
                    end
                    S_DATA_WRITE: begin
                        if (spi_phase == 1'b0) begin
                            spi_mosi <= test_pattern[bitcnt];
                            spi_clk <= 1'b0;
                            spi_phase <= 1'b1;
                        end else begin
                            spi_clk <= 1'b1;
                            spi_phase <= 1'b0;
                            if (bitcnt == 0) begin
                                state <= S_FINISH_WRITE;
                            end else begin
                                bitcnt <= bitcnt - 1;
                            end
                        end
                    end
                    S_FINISH_WRITE: begin
                        spi_clk <= 1'b0;
                        spi_csn <= 1'b1;
                        bitcnt <= 8'd10;
                        next_state <= S_START_READ;
                        state <= S_WAIT;
                    end
                    S_START_READ: begin
                        spi_csn <= 1'b0;
                        cmd_byte <= 8'h03; // READ
                        bitcnt <= 8'd7;
                        spi_phase <= 1'b0;
                        state <= S_CMD_READ;
                    end
                    S_CMD_READ: begin
                        if (spi_phase == 1'b0) begin
                            spi_mosi <= cmd_byte[bitcnt];
                            spi_clk <= 1'b0;
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

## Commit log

2026-04-19 brightness controlm through up and down buttons
2026-04-19 limit brightness to 15, anything els is nuts, and gets warm, and the 2A HW limiter for LED power kicks in
2026-04-19 limit brightness to 9 even, LED area feels > 60°C still, need to measure
2026-04-23 allow flashing of foreign bins, and to all slots
    make flash SLOT=2 BIN=/some/alien.bin
    which can then be booted by pressing btn_left during reset/power up.
    make flash SLOT=3 BIN=/home/brew.bin
    which can then be booted by pressing btn_right during reset/power up.
2026-07-17 add a PSRAM probe test
2026-09-25 moins de francais
2026-09-29 add kicad schematics, pcb, sch.pdf and renderings
    [bare_metal.kicad_pcb, bare_metal.kicad_sch, flash.kicad_sch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]
2026-09-30 add 3d screen step files
    [bare_metal_screen_2_1.step, bare_metal_screen_2_2.step, bare_metal_screen_2_3.step]
